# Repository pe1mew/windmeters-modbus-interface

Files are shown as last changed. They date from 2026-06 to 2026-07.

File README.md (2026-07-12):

# Windmeters Modbus Interface

A CH32V003-based interface board that bridges classic analog wind sensors —
a **cup anemometer** (reed-relay pulses) and a **wind-vane potentiometer**
(0–360°) — onto **Modbus RTU over RS-485**, powered by 24 V passive PoE and
designed for daisy-chained field buses.

One PCB serves both sensor types; the firmware build selects the variant.
Each variant responds at its own Modbus address, selected by a solder
jumper:

| Variant | Jumper open | Jumper bridged |
|---|---|---|
| Wind speed (`wind_speed`) | **30** | 35 |
| Wind direction (`wind_direction`) | **31** | 36 |
| Both, one slave (`wind_combined`) | **32** | 37 |

The `wind_combined` build serves both sensors through a single Modbus
address; its register map carries speed and direction at their own
register addresses, with the direction raw-ADC diagnostic at 30013 (30005
holds the speed pulse count).

## Project status (2026-07)

| Area | State |
|---|---|
| Requirements | [`design/TDS.md`](design/TDS.md) **v0.9** — 69 active requirements (incl. FR-S39 persistence, FR-S40 runtime calibration) + §4 as-built hardware from the KiCad PCB, hardened by multi-agent audits + verification passes |
| Drivers | Pulse counting, ADC/circular-mean, Modbus RTU — all HIL-verified on silicon ([`design/driverDevelopment.md`](design/driverDevelopment.md)) |
| Product firmware | Integration stages A–F complete; **TDS-functionally complete** on all three variants (speed, direction, combined), acceptance suite green ([`design/integrationPlan.md`](design/integrationPlan.md)) |
| Hardware/HIL | KiCad schematic/PCB in design; **§9.1 MAX3485-rig HIL complete on all three variants**; real-PCB rows (§9.2) pending |
| Release | Firmware version 1 not yet tagged ([`software/firmware/RELEASES.md`](software/firmware/RELEASES.md)) |

## Hardware

- **MCU**: WCH CH32V003J4M6 (RISC-V, SOP-8, 16 KB flash / 2 KB RAM) — the
  8-pin package drives the whole design: single-wire UART discipline,
  remap tricks, and a zero-interrupt firmware architecture
  ([`design/softwareArchitecture.md`](design/softwareArchitecture.md)).
- **RS-485**: MAX3485; DI+RO tied to PD6, DE+R̄Ē tied to PC2 with a 10 k
  pull-down (keeps the bus safe during reset/flashing); 120 Ω terminator
  behind a solder jumper; A/B fail-safe bias; SM712 TVS.
- **Power**: 24 V passive PoE on the spare pairs (4/5 = +, 7/8 = −) →
  DB207 bridge (polarity protection only) → HLK-K7803 buck → 3.3 V.
- **Connectors**: 2× RJ45 for the daisy-chained bus, two RJ14 sensor jacks
  (anemometer + wind direction), 3-pin header for the WCH-LinkE programmer
  (SWIO on PD1).

## Modbus register map (summary)

12 input registers (FC04) and 6 holding registers (FC03/06/16); registers
of an absent sensor read 0, and the combined build adds a 13th input
register (30013, direction raw ADC). Highlights: instantaneous and averaged
values, status bits, identification (build + firmware version), uptime,
CRC/served counters, gust, seconds-since-last-pulse.
**6** holding registers: direction offset, measurement window, averaging
window, low-speed cut-off, and the anemometer calibration (factor C +
pulses-per-rotation, FR-S40 — so one image serves any anemometer, set over
Modbus). All **persisted in flash across reset/power-loss** (FR-S39); the §2.8
defaults apply only on first boot / erased store. The authoritative map with
ranges, defaults, and requirement IDs is [`design/TDS.md`](design/TDS.md)
§2.7/§2.8.

## Repository layout

| Path | Contents |
|---|---|
| [`design/`](design/README.md) | The design-document chain (index in [`design/README.md`](design/README.md)): scratchBook → TDS → softwareArchitecture (+ UML diagrams in `design/diagrams/`) → driverDevelopment → integrationPlan |
| `hardware/KiCad/` | Schematic + PCB (KiCad); symbol libraries as git submodules |
| `hardware/Documentation/` | Component datasheets (HLK-K78xx, DB20x, Kradex enclosure, …) |
| `software/firmware/` | Product firmware (PlatformIO + ch32v003fun), three build envs (speed / direction / combined) + `_test` variants |
| `software/drivers/` | Standalone driver projects with HIL test shells (the verified libraries the product references in place) |
| `software/hil/` | Scripted hardware-in-the-loop harness: Saleae Logic 2 (MCP) + ADALM2000 (libm2k) + `acceptance/` pytest suite; consolidated [`testReport.md`](software/hil/testReport.md) |
| `Doxyfile` | Doxygen config — builds a single site (design docs + API reference) with this README as the landing page |
| `documentation/` | Chip pinout and project reference images |

Clone with submodules:

```sh
git clone --recurse-submodules https://github.com/pe1mew/windmeters-modbus-interface.git
```

## Building and flashing

Requires [PlatformIO](https://platformio.org/) and a WCH-LinkE on SWIO.

```sh
cd software/firmware
pio run -e wind_speed              # or wind_direction, or wind_combined
pio run -e wind_speed -t upload    # flash via WCH-LinkE
```

Resource ceilings (14 336 B flash / 1 792 B RAM, NFR-RES01) are enforced as
hard build gates. `*_test` environments add bench-only hooks — never
release those binaries. The firmware version byte lives in
`src/version.h`; the release process is documented in `RELEASES.md`.

## Testing

- **Host tests** (no hardware): the circular-mean math is exhaustively
  verified in Python — `python software/drivers/common/circmean/test_circmean.py`.
- **Acceptance suite** (bench: Saleae Logic 2 with its MCP server, ADALM2000,
  WCH-LinkE, TTL Modbus rig):

  ```sh
  cd software/hil/acceptance
  ..\.venv-m2k\Scripts\python.exe -m pytest . --build speed
  ```

  One command per flashed variant; covers the register map, protocol
  vectors, measurement services, averaging engine, version chain, and
  build gates. See [`software/hil/README.md`](software/hil/README.md) for
  instrument setup, wiring, and the bench-quirk catalogue.
- **HIL test report** — [`software/hil/testReport.md`](software/hil/testReport.md)
  consolidates every hardware-in-the-loop test (driver-phase, integration-
  stage, and MAX3485 transceiver rig) with its setup, expected result, and
  pass/fail verdict in one place.

## Documentation

- **Design record** — [`design/README.md`](design/README.md) indexes the
  document chain (requirements → architecture → drivers → integration) and
  the UML diagrams.
- **API + design site** — the firmware headers/sources carry full Doxygen,
  and [`Doxyfile`](Doxyfile) folds the design docs in as pages with this
  README as the landing page. Build the browsable HTML with:

  ```sh
  doxygen Doxyfile        # output in documentation/doxygen/html/index.html
  ```
- **Test evidence** — [`software/hil/testReport.md`](software/hil/testReport.md)
  is the consolidated hardware-in-the-loop test report.

## Related repositories

- [`pe1mew/windmeters-modbus-interface-tester`](https://github.com/pe1mew/windmeters-modbus-interface-tester) —
  the Modbus RTU master bench tool (M5Stack AtomS3 + RS-485) used to
  exercise this device; its bench findings seeded this project's TDS.

## License

Software is provided under a Source-Available Non-Commercial License;
documentation and images under CC BY-NC-ND 4.0. See [LICENSE](LICENSE) and
[license.md](license.md). Third-party datasheets and KiCad library
submodules remain under their owners' terms.

## Author

Remko Welling (PE1MEW)

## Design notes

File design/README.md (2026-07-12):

# Design documentation

This directory holds the design record for the Windmeters Modbus Interface
firmware — the chain from first idea to a validated, requirement-traced
implementation. The documents build on each other in this order:

```
scratchBook  →  TDS  →  softwareArchitecture  →  driverDevelopment  →  integrationPlan
(brainstorm)   (what)   (how + diagrams)         (drivers + results)   (product fw + results)
```

## The documents

| Document | Purpose | Status |
|---|---|---|
| [`TDS.md`](TDS.md) | **Technical Design Specification** — the requirements contract (FR-MB…, FR-S…, NFR-…) with measurable pass/fail criteria. The single source of truth for behaviour. | **v0.9** — 69 active requirements + §4 as-built hardware (from the KiCad PCB); hardened by a multi-agent audit + verification passes |
| [`softwareArchitecture.md`](softwareArchitecture.md) | **How** the requirements are met: the zero-ISR cooperative super-loop, the module split (capability-macro variant gating incl. `wind_combined`), and the sizing rationale with as-built numbers. §7 embeds the UML diagrams. | Agreed baseline; updated 2026-07-12 for the three-variant firmware |
| [`driverDevelopment.md`](driverDevelopment.md) | Plan + results for the three standalone drivers (pulse counting, ADC/circular-mean, Modbus RTU), each HIL-verified before integration. | Phases 0–3 complete, HIL-verified on silicon |
| [`integrationPlan.md`](integrationPlan.md) | The product-firmware plan: six integration stages (A–F) and the §9 hardware-gated test set (MAX3485 rig + real PCB). Carries per-stage results. | Stages A–F done; §9.1 complete on all three variants; §9.2 (real PCB) pending |
| [`scratchBook.md`](scratchBook.md) | The brainstorm and working notes that seeded the TDS — components, power chain, ADC strategy, calibration derivation. Superseded by the docs above where they overlap. | Working notes (historical) |
| [`diagrams/`](diagrams/) | UML diagrams as PlantUML sources + rendered PNGs (see below). | — |

## Diagrams

Three UML views of the shipped design live in [`diagrams/`](diagrams/) and
are embedded in [`softwareArchitecture.md`](softwareArchitecture.md) §7:

- **[`component.puml`](diagrams/component.puml)** — module structure & data
  flow (sensor → driver → measurement → `regs` hub → Modbus).
- **[`superloop_sequence.puml`](diagrams/superloop_sequence.puml)** — one
  zero-ISR super-loop iteration.
- **[`modbus_state.puml`](diagrams/modbus_state.puml)** — the Modbus RTU
  line-discipline state machine.

Regenerate the PNGs with the local PlantUML:

```sh
"C:/apps/plantuml/plantuml.exe" -tpng -o . design/diagrams/*.puml
```

## Build variants

The firmware compiles into three variants from one source tree (FR-S01),
selected by a `-D SENSOR_WIND_*` define and addressed by a PC4 solder jumper:

| Variant | Build type | Address (open / bridged) |
|---|---|---|
| `wind_speed` | 0x01 | 30 / 35 |
| `wind_direction` | 0x02 | 31 / 36 |
| `wind_combined` | 0x03 | 32 / 37 |

## How this connects to the rest of the repo

- The **API reference** ([`Doxyfile`](../Doxyfile) at the repo root) folds
  these design documents in as pages alongside the header/source
  documentation — run `doxygen Doxyfile` for a single browsable site with
  the project [`README.md`](../README.md) as its landing page.
- The requirements here are verified by the scripted bench in
  [`software/hil/`](../software/hil/); every executed test with its
  setup/expected/verdict is consolidated in
  [`software/hil/testReport.md`](../software/hil/testReport.md).
- Contribution workflow (requirements-first, build all variants, run the
  host + acceptance tests) is in [`contributing.md`](../contributing.md).

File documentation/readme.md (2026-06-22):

# WCH MCU documentation on the web

 - https://github.com/limingjie/WCH-MCU-Pinouts/tree/main

# Source downloaded PDF

 - https://www.olimex.com/Products/RISC-V/WCH/WCH-LinkE/resources/WCH-LinkUserManual.PDF
 
# Wiring WCH-Link 

## to nanoCH32V003

```
        nanoCH32V003             WCH-LinkE
      +--------------+    +----------------+
      |              |    |                |
      |          GND o----o GND            |
      |          DI0 o----o SWDIO/TMS      |
      |          VCC o----o 3V3            |
      |              |    |                |
      +--------------+    +----------------+
```

## CH32V003 J4M6 D03

You need a WCH-LinkE programmer to flash this MCU. You connect SWIO to PD1 (pin 8), VDD to pin 4 and VSS to pin 2.

```
     CH32V003J4M6D03             WCH-LinkE
   +-----------------+    +----------------+
   |                 |    |                |
   |         VSS (2) o----o GND            |
   |         PD1 (8) o----o SWDIO/TMS      |
   |         VDD (4) o----o 3V3            |
   |                 |    |                |
   +-----------------+    +----------------+
```

# Platformio an the WCH CH32V Platform

 - https://ch405labs.net/ch32v003_intro/

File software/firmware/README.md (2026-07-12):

# Firmware — Windmeter Modbus interface

PlatformIO project for the **CH32V003J4M6** (RISC-V, SOIC-8, 16 KB flash /
2 KB RAM). One unmodified PCB runs every variant; the sensor build is chosen
at compile time (TDS FR-S01/FR-S02).

Authoritative references: the register map and behaviour contract live in
[`design/TDS.md`](../../design/TDS.md) (§2.7 input / §2.8 holding registers,
§4 as-built hardware and pin assignment); the zero-ISR super-loop design and
module split in
[`design/softwareArchitecture.md`](../../design/softwareArchitecture.md).

## Build environments

| Environment | Define | Sensor(s) | Build byte | Address (PC4 open / bridged) |
|---|---|---|---|---|
| `wind_speed` | `SENSOR_WIND_SPEED` | cup anemometer | `0x01` | **30** / 35 |
| `wind_direction` | `SENSOR_WIND_DIRECTION`  | wind-vane potentiometer | `0x02` | **31** / 36 |
| `wind_combined`  | `SENSOR_WIND_COMBINED` | both, behind one slave | `0x03` | **32** / 37 |

`sensors.h` maps the selector onto capability macros
(`HAVE_WIND_SPEED` / `HAVE_WIND_DIRECTION`); the combined build defines both.
Each variant also has a **`*_test`** environment adding `-D TEST_HOOKS` — the
FR-S20 watchdog hang trigger (holding `0x00FF`, magic `0xDEAD`) used by the
HIL persistence/reset checks. **Never release a `*_test` binary.**

## Prerequisites

- [PlatformIO Core](https://platformio.org/install/cli) (`pip install platformio`)
  or the PlatformIO VS Code extension.
- A **WCH-LinkE** programmer on SWIO (PD1, the 3-pin header J2).

The community WCH platform (`platform = ch32v`) and the `ch32v003fun`
framework are pulled automatically on first build. The verified driver
libraries (`ws_*`, `wd_*`, `mb_*`, `circmean`) are referenced **in place**
from [`software/drivers/`](../drivers/) — no copies.

## Usage

```sh
pio run                            # build default env (wind_speed)
pio run -e wind_combined           # build the combined variant
pio run -e wind_combined -t upload # flash via WCH-LinkE
```

There is no serial console: the release firmware never transmits unsolicited
(FR-S19) — PD6 is the Modbus data line. Talk to a flashed device over
RS-485/Modbus RTU (9600 8N1), e.g. with the
[`windmeters-modbus-interface-tester`](https://github.com/pe1mew/windmeters-modbus-interface-tester)
as master.

## Resource ceilings (NFR-RES01)

The 87.5 % ceilings — **14 336 B flash / 1 792 B RAM** — are hard build gates
(`board_upload.maximum_size` / `maximum_ram_size`); a build that exceeds them
fails. As-built (fw v1, with FR-S39 persistence + FR-S40 calibration):

| Variant | Flash | RAM |
|---|---|---|
| `wind_speed` | 4 408 B (31 %) | 908 B (51 %) |
| `wind_direction` | 6 824 B (48 %) | 916 B (51 %) |
| `wind_combined` | 7 604 B (53 %) | 1 216 B (68 %) |

## Configuration and calibration

All six holding registers (40001–40006) are runtime-writable and **persist in
flash across reset/power-loss** (FR-S39). The anemometer calibration
(FR-S40) is register-driven — factor C in 40005, pulses-per-rotation in
40006 — so one binary serves any anemometer with no rebuild. The compile-time
defaults that seed those registers on first boot can be overridden per build:

```ini
build_flags = ... -D WS_C_SCALED=980 -D WS_PULSES_PER_ROTATION=1
```

## Versioning and releases

The firmware version byte (reported in input register 30007, low byte) has a
single source: [`src/version.h`](src/version.h). Releases are registered in
[`RELEASES.md`](RELEASES.md); firmware version 1 will be tagged `fw-v1`.

## Testing

- **Host tests** (no hardware): `python ../drivers/common/circmean/test_circmean.py`.
- **Acceptance suite** (bench, one command per flashed variant):

  ```sh
  cd ../hil/acceptance
  ..\.venv-m2k\Scripts\python.exe -m pytest . --build combined
  ```

  Instrument setup, wiring, and the bench-quirk catalogue are in
  [`software/hil/README.md`](../hil/README.md); every executed HIL test with
  its verdict is consolidated in
  [`software/hil/testReport.md`](../hil/testReport.md).

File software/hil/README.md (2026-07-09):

# HIL test harness

Scripted hardware-in-the-loop testing per `design/driverDevelopment.md` §2.3/§2.5:
flash (`pio`) → stimulate (ADALM2000 / libm2k) → observe (Saleae Logic 2 MCP)
→ assert (Python).

> **Consolidated results:** [`testReport.md`](testReport.md) is the single
> record of every HIL test with its setup, expected result, pass criteria,
> and verdict. This README covers *how* to run the harness (instruments,
> wiring, quirks); the test report covers *what was tested and the outcome*.
> Regenerate the report when the check scripts or the design docs change.

## Instruments

| Instrument | Interface | Role |
|---|---|---|
| Saleae Logic16 (classic, digital-only) | Logic 2 built-in MCP server, `http://127.0.0.1:10530/mcp` (JSON-RPC/HTTP) | Observer: digital captures, protocol analyzers, CSV export |
| ADALM2000 (M2K) | libm2k (Python 3.11 venv) | Stimulus: pulse trains, bursts, DC levels/ramps, programmable supply; its scope verifies analog |
| WCH-LinkE | `pio run -t upload` (`%USERPROFILE%\.platformio\penv\Scripts\pio.exe`) | Flash + 3.3 V DUT power + UART monitor RX |

## Python environments

- Saleae scripts are **stdlib-only** — any Python ≥3.10 works (system 3.13 fine).
- libm2k wheels top out at **cp311**, and the wheel alone is not enough —
  it needs the system-installed libm2k/libiio DLLs. Setup (one-time):
  1. Run `PlutoSDR-M2k-USB-Drivers.exe` (admin) — IIO/RNDIS USB drivers.
  2. Run `libm2k-0.9.0-Windows-setup.exe` (admin) — runtime DLLs.
  3. `python3.11 -m venv .venv-m2k` and
     `.venv-m2k\Scripts\pip install libm2k-0.9.0-cp311-cp311-win_amd64.whl`
     (wheel from the libm2k GitHub release `python-wheels.zip`).

## Scripts

| Script | Purpose | Status |
|---|---|---|
| `smoke_test.py` | Saleae MCP link: devices, capture, export | PASS 2026-07-03 |
| `blinky_check.py` | Flash→capture→assert chain on the DUT (blinky timing) | PASS 2026-07-03 (ch8) |
| `uart_check.py` | debug_uart §2.2 exit criterion (async-serial decode) | PASS 2026-07-03 |
| `m2k_smoke.py` | M2K reachable, calibrated, subsystems up | PASS 2026-07-03 (fw v0.33) |
| `m2k_signal_check.py` | Generate + verify every driver-phase stimulus signal | PASS 2026-07-03, 15/15 |
| `saleae_serial.py` | Shared module: UART capture + timestamped line decode | library |
| `ws_check.py` | Wind speed driver phase-1 matrix (counts, duty, timing, saturation) | PASS 2026-07-03, 9/9 |
| `wd_check.py` | Wind direction phase-2 matrix (AWG-based; superseded for accuracy rows by the divider method — see README notes) | superseded 2026-07-03 |
| `mb_check.py` | Modbus RTU phase-3 matrix (26 vectors, TDS §2) + timing; M2K as open-drain bit-banged master | PASS 2026-07-03, 26/26 + 40/40 endurance |
| `rs485_check.py` | MAX3485-rig passive judge of live master traffic: DE timing, storm, idle-bias, latency, wire CRC both directions | PASS 2026-07-06, 8/8 (117 transactions) |
| `rs485_regs_check.py` | Full TDS §2.7/§2.8 register read/write matrix over RS-485 via the tester's machine API; `--build speed\|direction\|combined` | PASS: speed 62/62, direction 72/72 (2026-07-06), **combined 77/77** (2026-07-08, `--speed-live`) |
| `rs485_raw_check.py` | Byte-exact §9.1 vectors via second-MAX3485 raw master: split frames, garbage floods, off-baud, 1000-request latency histogram | PASS 2026-07-06, all groups (both builds) |
| `m2k_pulse.py` | M2K W2 (AWG) → PC1 speed pulse train; holds the context open (+V+ keepalive) so another process runs the matrix concurrently | used for combined `--speed-live` |
| `rs485_float_check.py` | FR-S38 wind-direction float-fault + recovery over RS-485 (`--expect fault\|driven`, `--build direction\|combined`) | PASS 2026-07-08, fault 4/4 + recovery 4/4 |
| `rs485_persist_check.py` | FR-S39 holding-register persistence across a watchdog reset (`*_test` build); write → reset → assert settings survive | PASS 2026-07-08, 7/7 |
| `m2k_vplus_check.py` | DUT powered from M2K V+: ratiometric ADC VDD sweep (P2-WD-RATIO) + FR-S39 persistence across a real power cycle. Guards against driving V+ into a live LinkE rail | PASS 2026-07-09, 6/6 |

## Bench wiring notes

- Saleae Logic16 lead labels ≠ channel indices (two 8-lead banks). DUT PD6
  is currently on **channel 8**. After rewiring, locate signals with an
  all-channel sweep capture first.
- `m2k_signal_check.py` rig: M2K DIO0 → Saleae **channel 15** (current bench);
  M2K W1 → M2K 1+; M2K V+ → M2K 2+; all grounds common (M2K, Saleae, LinkE,
  DUT).
- Keep M2K AWG outputs configured 0–3.3 V near the DUT (hardware can swing
  ±5 V — beyond CH32V003 absolute maximums).
- **MAX3485 rig (2026-07-06)**: DUT transceiver DI+RO → PD6 (Saleae ch8 on
  that node), DE+R̄Ē → PC2 (ch15) with the 10 k pull-down; bus A/B → M2K
  scope 1+/2+ for the analog wire view. **Second MAX3485 as raw master**:
  M2K DIO0 → DI, DIO1 → DE+R̄Ē, **V+ → VCC (3.3 V)** — every raw-master
  script must enable V+ itself (`ps.enableChannel(0, True)` +
  `pushChannel(0, 3.3)`): an unpowered MAX3485 sits inert and the static
  DE/DI test (drive space, drive mark, release) is the 10-second wiring
  proof. The `windmeters-modbus-interface-tester` on the same bus is both
  a third node and a scriptable well-formed master (machine API, see its
  `manual/api.md`).

## MAX3485-rig lessons (2026-07-06, learned the hard way)

- **The tester never stops listening.** Its Modbus master only drains its
  UART RX during its own transactions, so it buffers every byte the raw
  master puts on the shared bus; its next transaction then parses the
  stale backlog and reports CRC_ERR (log showed ~30 overheard frames
  ahead of the true response). One throwaway read IS the flush — retry
  once on `crc_error` before trusting a tester-API read after raw-master
  traffic (`rs485_raw_check.dut_diag`).
- **Inter-frame marks in composed patterns must exceed t3.5 (4.01 ms).**
  A 2.5 ms gap between a garbage tail and the recovery request made the
  DUT (correctly) coalesce them into one discarded frame — 48 bit times
  of mark (5 ms) is the house gap.
- **Noise floods don't move the DUT's CRC counter** — random bytes arrive
  framing-poisoned (FE/overflow) and take the silent-discard path;
  only cleanly-framed-wrong-CRC frames (e.g. split halves) increment
  30009. Assert flood recovery by behavior, not by that counter.
- The DUT answers master baud offsets to ±3 % in both directions
  (measured with the rate read back from the ladder); its own HSI adds
  ~+0.3 %.

## M2K / libm2k quirks (learned on the bench, fw v0.33 + libm2k 0.9.0)

- **Firmware ≥0.32 is mandatory** for libm2k 0.9.0 (shipped fw v0.27 gave
  erratic AWG output and version errors). Update: copy `m2k.frm` from the
  m2k-fw release onto the M2K mass-storage drive and eject; it self-flashes
  (~1 min, don't unplug).
- **Analog-out session-state corruption**: within one context, repeated
  output reconfiguration misbehaves — `stop()` wedges the DAC until
  `reset()`; a second cyclic `push()` at the same sample rate is silently
  ignored; non-cyclic pushes and `setVoltage()` inherit stale state. The
  reliable pattern is a **fresh `m2kOpen()` + calibrate per analog stimulus
  configuration** (~1.5 s each). Digital out is unaffected.
- Rapid close/reopen can transiently fail ("Cannot set the number of kernel
  buffers") — retry with ~1 s backoff (`open_calibrated()` helper).
- **Pattern generator start stub**: the first period after `push()` is
  anomalous; frequency/duty measurements must judge steady state only.
- **Large cyclic digital buffers get truncated** (1 Hz @ 1 MS/s ran 6%
  fast) — scale the sample rate to keep one period at ~10k samples.
- AWG sample rates snap to a discrete ladder (75 MS/s / 10ⁿ); at low rates
  the DC output droops between buffer wraps — generate DC at 750 kS/s or
  via `setVoltage()`.
- Absolute AWG+scope accuracy stacks badly — DMM-anchored on this unit:
  the **AWG outputs setpoint +25 mV** (constant), the **scope reads
  ~1%/−30 mV low** (affine, drifts ~10 mV between sessions). Never assert
  DUT accuracy against M2K absolute voltages; use a **resistor divider
  from DUT VDD** (ratiometric, DMM-measured ratio) as the method of
  record. The M2K remains fine for dynamics, end stops, and anything
  ratio-cancelled.
- **Keep the libm2k context OPEN while the DUT-side capture runs**:
  `contextClose()` idles the AWG outputs. Measure-then-close-then-capture
  silently tests a dead stimulus (cost a full debugging afternoon).
- A "disabled" AWG channel is NOT high-impedance (~50 Ω to its idle
  level) — it cannot emulate a disconnected sensor for float-detection
  tests; physically lift the wire instead.

## Saleae MCP quirks (learned on the bench)

- `add_analyzer` settings need tagged values: `{"Input Channel": {"numberValue": 8}}`.
- `export_raw_data_csv` requires `analogDownsampleRatio` even for digital-only.
- Async-serial data-table CSV holds the *literal* character per byte — CR/LF
  arrive as embedded newlines inside quoted fields; don't strip.
- A capture that starts mid-byte yields garbage + one framing error before
  the first line boundary — judge from the first clean `\n` onward.
- Classic Logic16 rejects `digitalThresholdVolts` values — omit it (default
  range suits 3.3 V logic).

## Modbus TTL-rig lessons (phase 3, learned the hard way)

- **The Logic 2 Async Serial analyzer is unreliable at 9600 baud** on this
  setup — byte values scramble while the raw edges are perfect. Binary
  protocols use `saleae_serial.uart_decode()` (software UART over the raw
  edge export) instead. Also: `decode_events(..., sync_to_newline=False)`
  for binary — the text-protocol first-LF rule silently discards
  LF-free captures.
- **M2K as shared-wire master: use open-drain output mode**
  (`setOutputMode(DIO_OPENDRAIN)` + the external pull-up), permanently
  enabled. The tristate dance (direction flips per transaction) sprays
  break glitches and phantom start bits; `push()` starts can still glitch —
  keep a ~10 ms driven-high lead-in so any phantom byte orphans behind a
  t3.5 gap.
- **A master must release the wire immediately after its last stop bit** —
  the DUT replies ~5 ms later; holding the line driven collides with the
  reply.
- DUT-side registers exposing error counters and a last-bad-frame stash
  are worth their flash cost many times over: the stash is what proved
  "first byte swallowed" and later "ISR corruption" beyond argument.

## DUT-side UART gotchas (learned on the bench)

- **HDSEL idles the line floating**: in half-duplex mode the USART releases
  TX between frames; a lightly-loaded pin drifts low and every following
  frame decodes with framing errors. `common/debug_uart` therefore runs
  plain TX (idle mark driven). Continuous streams mask this — it only bites
  bursty output.
- **HDSEL also intermittently swallows the first RX byte after idle**
  (~35%, no error flags) — the Modbus driver abandoned HDSEL entirely for
  a remap-switching discipline (RX on PD6 via the default map; TX remapped
  in only for the response). See `software/drivers/modbus_rtu/README.md`.
- **Interrupts are suspect on this toolchain path**: an RXNE ISR corrupted
  ~1/3 of received frames with no USART error flags; polled RX fixed it
  outright. The architecture is now zero-ISR
  (`design/softwareArchitecture.md`) — root-cause before ever adding one.
- **ch32v003fun SysTick default is HCLK/8**: define
  `FUNCONF_SYSTICK_USE_HCLK 1` when pacing with raw `SysTick->CNT` math, or
  everything runs 8× slow.
- Count-vs-frequency asserts must scale to the **measured** window duration
  (report-line timestamp deltas): the DUT window is HSI-paced (±1%), so at
  1 kHz a nominal-window compare is off by several counts while the DUT is
  behaving exactly per FR-S06.

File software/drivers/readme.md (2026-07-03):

# Drivers for CH32V003J4M6

Here are the individual drivers for teh project using a CH32V003J4M6.

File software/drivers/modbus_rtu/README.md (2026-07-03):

# Modbus RTU slave driver — USART1 on PD6, DE/RE on PC2

Phase-3 driver per `design/driverDevelopment.md` §5. Implements the TDS §2
driver layer: framing/CRC, t3.5 gap detection, address filtering,
FC03/04/06/16, standard exceptions, no-clamp range rejection, atomic FC16,
quantity validation, big-endian data / little-endian CRC, FC06 echo & FC16
confirm responses, and app-owned register semantics (holding table with
min/max, input-read callback, cross-validate hook for FR-S31).

## HIL verification — PASS 2026-07-03 (TTL rig, no transceiver)

`software/hil/mb_check.py`, M2K as bit-banged open-drain master on the
shared PD6 wire, Saleae raw-edge decode:

- **26/26 matrix vectors** covering FR-MB02/05/06/08–15/19/22/25/28/30 and
  FR-S31 cross-register constraint via the hook
- **40/40 endurance transactions**, zero loss
- **Response latency: median 5.2 ms, worst 5.2 ms** (FR-MB21 typical <15 ms,
  FR-MB20 hard <100 ms)

Deferred to the MAX3485 rig / acceptance: FR-MB04 DE-timing scope asserts
(PC2 is on Saleae ch15, not yet asserted), FR-MB24 garbage-flood and
oversize-frame vectors, FR-MB03 split-frame timing vectors, RS-485
electrical rows.

## Two hard-won design decisions (bench-forced, both product-relevant)

**1. No HDSEL — remap-switching line discipline.** In HDSEL single-wire
mode this part intermittently (~35%) swallowed the FIRST byte after bus
idle with no error flags (wire verified pristine at 10 MS/s; the stashed
frame was the request minus its address byte). Instead the driver uses the
SOP-8 remap geometry: the DEFAULT USART map has **RX natively on PD6**;
`mb_send()` temporarily switches to partial remap 2 (TX→PD6), transmits,
and switches back. Modbus is strictly request/response, so the direction is
always known. Side benefit: no self-echo during reception (FR-MB23
satisfied by flag-clearing around the TX window).

**2. Polled RX — zero interrupts.** With the RXNE ISR, ~1/3 of frames
reached the parser with missing/scrambled leading bytes while the USART
never flagged an error — symptoms of ISR prologue/state corruption on this
toolchain path (`__attribute__((interrupt))` on RV32EC, unconfirmed root
cause; treat ANY interrupt use in this project as suspect until
investigated). Polling from the main loop (~1 µs cycle vs 1042 µs per
byte) is provably lossless and removed every failure instantly:
26/26 + 40/40 vs the ISR build's chaos. `softwareArchitecture.md` is
amended accordingly.

## Diagnostics (exposed as shell input registers)

`mb_crc_error_count` / `mb_served_count` (future 30009/30010), plus bench
registers: FE/NE/ORE counters and a last-CRC-fail frame stash (len, first
bytes, received CRC) — the stash is what cracked the first-byte-loss hunt.

## API (`lib/mb/`)

```c
mb_config_t cfg = {.address, .holdings, .n_holdings,
                   .input_read, .cross_validate};
void mb_init(const mb_config_t *cfg);
void mb_poll(void);   // main loop; self-timed via SysTick->CNT
```

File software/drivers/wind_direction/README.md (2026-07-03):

# Wind direction driver — 10-bit ADC on PA2, oversampled, circular mean

Phase-2 driver per `design/driverDevelopment.md` §4. Reads the wind-vane
potentiometer ratiometrically (TDS FR-S09), 16× oversampled (FR-S28), with
wiper-float detection (FR-S38). The circular mean lives in
`software/drivers/common/circmean/` (Q15 sine table + integer CORDIC,
exhaustively host-tested + boot self-test on target).

## HIL verification — PASS 2026-07-03

Method of record for accuracy: **resistor divider powered from DUT VDD**
(ratiometric, cancels VDD, kΩ source like the real pot — exactly FR-S11's
method). AWG-based absolute-voltage tests proved unusable for accuracy: the
M2K AWG has a +25 mV output offset and the M2K scope reads ~1%/−30 mV low
(both DMM-anchored), stacking to a fake ±16 LSB "bow".

| Row | Result |
|---|---|
| Accuracy (FR-S11) | −3.8 LSB at divider ratio 0.49899 (9.92k/9.88k, DMM-measured); budget ±10 LSB. Full 5-ratio sweep deferred to acceptance. |
| Stability (FR-S10/S28) | raw16 span 0.6 LSB over 11 s (≤3 required) |
| End stops (FR-S09) | pin→GND: code 0.0; pin→VDD: code 1023.0 — exact |
| Never 3600 (FR-S29) | angle 3596 at the VDD rail, by construction |
| Float detect (FR-S38) | truly open pin: flt=1 every window; pot-like 4.95 kΩ source: flt=0; 50 Ω source: flt=0 |
| Circular mean (FR-S14) | host: identity 0 LSB over all 3600 angles, CORDIC ≤0.0035°, 350°/10°→0.0°; on-target boot self-test CM,PASS |

Deferred to integration/acceptance: 5-ratio accuracy sweep, M2K-powered VDD
sweep (explicit ratiometric-sanity row), offset register wrap via Modbus
(FR-S12 — logic host-proven).

## Bench findings that shaped the driver

- **ADC clock**: HCLK/8 = 6 MHz (`RCC_ADCPRE_DIV8` — the ADCPRE field is
  NOT a plain binary divider; use the named constants). At /2 = 24 MHz the
  part appeared to bow at range ends; later attributed mostly to
  instrument stack, but /8 costs nothing here (~14 µs/conversion, 224 µs
  per 16-burst vs the 100 ms update budget).
- **Float detector**: pull-toggle with 10 µs settle discriminates cleanly:
  truly open pads swing >700 LSB; a 5 kΩ pot moves ~100 LSB (threshold 300).
  A "disconnected" AWG does NOT read as floating — its disabled output is
  still ~50 Ω.
- **The angle mapping never emits 3600**: (raw16×3600+8192)>>14 tops out
  at 3596 at code 1023 — verified at the rail.

## API (`lib/wd/`)

```c
void     wd_init(void);            // ADC on, self-calibrated, 73-cycle sampling
uint16_t wd_read_raw16(void);      // sum of 16 conversions: 0..16368
uint16_t wd_angle_0_1deg(uint16_t raw16, uint16_t offset_0_1deg); // 0..3599
bool     wd_wiper_floating(void);  // FR-S38 pull-toggle test
```

## Test shell output (PD6 debug UART, 115200)

```
CM,PASS               boot self-test of circmean on the target CPU
WD,START
D,<raw16>,<inst>,<avg>,<flt>    per second; angles in 0.1°
```

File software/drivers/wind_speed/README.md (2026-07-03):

# Wind speed driver — TIM2 ETR pulse counting on PC1

Phase-1 driver per `design/driverDevelopment.md` §3. Counts anemometer
reed-relay pulses in hardware (zero CPU per pulse, TDS FR-S04) using TIM2 in
external-clock mode 2 on PC1.

## HIL verification — PASS 2026-07-03 (9/9)

`software/hil/ws_check.py`, M2K DIO0 driving PC1, report stream decoded off
the Saleae:

| Row | Result |
|---|---|
| Counts 1 / 10 / 100 / 1000 Hz | exact, scaled to the measured window |
| Rising edges only (10% / 90% duty) | identical counts (FR-S04) |
| Window pacing | worst 3.35 ms deviation on 1000 ms = 0.34% (FR-S17 ±2%) |
| Saturation (100 kHz × 1 s = 100k edges) | reports 65535 + `S` flag, never a wrapped value (FR-S27) |
| Silence (line low / open with pull-up) | 0 counts |

Outstanding (hardware-dependent): reed-relay bounce realism through the RC
debounce — run when a physical reed relay is on the rig.

## The remap (the phase's big unknown — confirmed on silicon)

`AFIO_PCFR1[9:8] = 10` (TIM2 partial remap 2) places TIM2_CH1/ETR on PC1 —
the only mapping that reaches PC1 on the SOP-8. Configured in `ws_init()`
with a read-modify-write that preserves the USART1 remap bits. TIM2 then
runs in external clock mode 2 (`SMCFGR = TIM_ECE`, rising edges, no input
filter — the product's RC network debounces externally).

## API (`lib/ws/`)

```c
void     ws_init(void);                   // remap + counter running
void     ws_window_start(void);           // CNT=0, clear UIF
uint16_t ws_window_read(bool *saturated); // count; 65535 + flag if UIF set
```

Window pacing is the caller's job (test shell here: SysTick-paced 1000 ms,
`FUNCONF_SYSTICK_USE_HCLK 1` — ch32v003fun's default SysTick clock is
HCLK/8, which silently makes naive tick math 8× slow).

## Test shell output (PD6 debug UART, 115200)

```
WS,START
W,<count>,<flag>      one line per window; flag 0 normal, S saturated
```

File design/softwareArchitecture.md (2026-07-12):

# Software Architecture — Windmeters Modbus Interface

| Field | Value |
|---|---|
| Document | Software architecture (design rationale) |
| Project | `windmeters-modbus-interface` firmware |
| Date | 2026-07-03 (combined-variant update 2026-07-12) |
| Status | Agreed baseline for driver development and integration; updated for the shipped three-variant firmware |
| Related docs | `design/TDS.md` v0.9 (requirements this design satisfies), `design/driverDevelopment.md` (drivers are written against this architecture), `design/integrationPlan.md` §10 (combined variant), `design/scratchBook.md` |

## 1. Scope and constraints

Target: CH32V003J4M6 — RV32EC, one core, 48 MHz HSI, 16 KB flash, 2 KB SRAM.
One firmware source tree, three builds (wind speed / wind direction /
combined, FR-S01). `sensors.h` maps the single `SENSOR_WIND_*` build
selector onto **capability macros** — `HAVE_WIND_SPEED` /
`HAVE_WIND_DIRECTION` — and the combined build simply defines both, so
every per-sensor block compiles in unchanged; nothing below is
combined-specific except where marked.

Given these constraints and the TDS requirements, the architecture is
**zero-interrupt: a cooperative super-loop polls everything.** No RTOS —
it would cost more RAM than the application uses and buys nothing here.

> **Amendment 2026-07-03 (phase-3 bench):** the original design used a
> USART RX ISR + SysTick ISR. On the bench, the RXNE ISR corrupted ~1/3 of
> received frames (missing/scrambled leading bytes, no USART error flags,
> wire verified pristine) — symptoms consistent with interrupt
> prologue/state corruption on this RV32EC toolchain path. Polled RX fixed
> it completely (26/26 matrix + 40/40 endurance). Since the main loop
> cycles in ~1 µs versus 1042 µs per byte at 9600 baud, polling is
> provably lossless and interrupts buy nothing. **Do not introduce ISRs in
> this project without first root-causing that failure** (suspect
> `__attribute__((interrupt))` code generation with ch32v003fun).

## 2. Structure

```
┌─ main loop (everything, run-to-completion, no ISRs) ────────┐
│ for(;;) {                                                   │
│   modbus_service();      // poll RXNE/errors, stamp ticks,  │
│                          // gap detect, parse, respond      │
│   measurement_service(); // per capability macro: speed     │
│                          // and/or direction — a combined   │
│                          // build runs BOTH in this pass    │
│   diagnostics_service(); // uptime, counters                │
│   IWDG_refresh();        // only here (FR-S20)              │
│ }                                                           │
└─────────────────────────────────────────────────────────────┘
   TIM2 (speed/combined): pure hardware counter — counts with zero code
   Timing: raw SysTick->CNT arithmetic (HCLK; FUNCONF_SYSTICK_USE_HCLK 1)
```

Initialization before the loop follows the FR-S18 order strictly:
PC2/DE low first → PC4 address latch → sensor front-end ready (ADC
self-calibration / TIM2 clear) → IWDG on → USART1 receiver enabled last.

*See §7 (below) for the component, super-loop sequence, and Modbus
state-machine diagrams.*

## 3. Key decisions and why

**Everything stateful lives in the main loop.** Modbus registers are written
by `measurement_service()` and read by `modbus_service()` — both in the same
sequential loop, so FR-S24's snapshot coherence is *structural*: no masking,
no double-buffering, no races, because there is no preemption between
producer and consumer. This is the single biggest simplification available,
and it is why measurement does **not** run in the SysTick ISR (superseding
the earlier scratchBook sketch that put it there).

**Frame boundary by polling, not a timer.** The main loop checks
`ms_tick - last_rx_tick ≥ 5` to detect the 3.5-character gap (FR-MB03). A
dedicated t3.5 timer interrupt is the textbook approach, but timers are
scarce (TIM2 is the pulse counter on the speed and combined builds), the
loop iterates thousands of times per millisecond, and the detection jitter
this adds is microseconds against a 100 ms budget (FR-MB20). One mechanism,
all three builds.

**Blocking TX from the main loop.** The longest response (~29 bytes) takes
~33 ms of wire time at 9600 baud. Sending it byte-by-byte with a poll on
TXE, then polling TC to drop DE within one character time (FR-MB04), is
simple and deterministic. It briefly stalls the loop, but well inside the
IWDG window, and Modbus is strictly request/response so nothing else can
arrive meanwhile. Self-echo cannot occur at all in the shipped design: the
remap-switching line discipline (RX native on PD6; TX remapped onto PD6
only for the response, RO tri-stated while DE is high — the HDSEL sketch
was abandoned per the §1 amendment) leaves nothing looped back, and the
receiver re-arms only after DE drops plus a t3.5 idle (FR-MB23).

**No ADC interrupt, no TIM2 interrupt.** Direction path
(direction/combined): every 100 ms the main loop takes 16 blocking
conversions (< 1 ms total at the ≥71-cycle sample time) and folds them per
FR-S28. Speed path (speed/combined): TIM2 counts in hardware; at window
expiry the main loop reads CNT, checks the overflow flag UIF for FR-S27
saturation (no ISR needed — poll the flag at read time), resets, computes,
publishes.

**Combined build: both sensors, one slave, zero new mechanism.** The
capability macros compile *both* measurement services into the same
super-loop pass — they run sequentially, so FR-S24's structural coherence
holds unchanged and there is still no concurrency surface. Each sensor gets
its own averaging cursor in `avg.c` (the two boxcar rings advance
independently, since the speed ring fills per measurement window and the
direction ring per 100 ms update). The extra work per pass is the ADC burst
(< 1 ms) plus the window computation — microseconds-scale against FR-MB20's
100 ms budget; measured response latency through the transceiver is
unchanged (~4.1 ms median). The register image carries both sensors at
their §2.7 addresses; the only map difference is the shared raw-diagnostic
slot: 30005 reports the speed pulse count on a combined build, and the
direction raw ADC moves to the combined-only 30013 (`regs.c`, the one
`SENSOR_WIND_COMBINED`-specific piece of code). Address pair 32/37
(`board.h`, FR-S03).

## 4. Shared state — the complete list

With zero interrupts there is **no concurrency surface at all**: every
variable has exactly one execution context. The RX buffer, tick stamps,
register image, and averaging blocks are all plain main-loop state.
FR-S24's snapshot coherence is absolute by construction.

## 5. Sizing sanity check

**RAM:** 256 B RX + 64 B TX + ~32 B register image + 256 B averaging blocks
(64 × two u16, per FR-S31's two-stage boxcar) + ~512 B stack ≈ **1.1 KB**,
inside NFR-RES01's 1792 B ceiling.

**Flash:** Modbus core ~2–3 KB, bitwise CRC-16 (~100 B — speed is
irrelevant at 9600 baud), fixed-point sin/cos table + CORDIC atan2 for the
circular mean ~1 KB, measurement logic ~1 KB — comfortable in NFR-RES01's
14 336 B ceiling (note: RV32EC has no hardware multiply/divide; libgcc soft
routines are pulled in by the FR-S06 math).

**Latency:** response starts ~5 ms after the frame gap in the typical case
(worst loop iteration is the window-boundary computation, well under 1 ms)
— meets FR-MB21's 95%-within-15 ms with margin, and FR-MB20's 100 ms hard
limit trivially.

**As-built (2026-07-12, fw v1 with FR-S39 persistence + FR-S40
calibration):** speed 4 408 B flash / 908 B RAM; direction 6 824 B / 916 B;
combined 7 604 B / 1 216 B — the largest build sits at 53 % of the flash
ceiling and 68 % of the RAM ceiling (NFR-RES01), so the estimates above
held and the combined variant fits with headroom. Measured latency through
the MAX3485: median 4.12 ms over 1 000 requests (`testReport.md`
R485-LAT-10D).

## 6. Module split

| Module | Contents | Driver-plan origin |
|---|---|---|
| `main.c` | The super-loop and window pacing | integration phase |
| `board.c` | Clocks, GPIO, FR-S18 init order, PC4 address latch, IWDG + PVD | integration phase |
| `sensors.h` | Build selector → capability macros (`HAVE_WIND_SPEED` / `HAVE_WIND_DIRECTION`) + `BUILD_TYPE`; a combined build defines both | integration phase (combined variant) |
| `mb.c` | Framing, CRC, FC dispatch, exceptions, DE control + remap-switching line discipline — referenced in place from `software/drivers/modbus_rtu` | `modbus_rtu` driver (`mb_*`) |
| `regs.c` | Register image + table-driven `{addr, min, max}` validator — FR-MB19/22/28 become one code path; persist load/save wiring; the 30005/30013 combined split | integration phase |
| `meas_speed.c` | TIM2 ETR counting, FR-S06/S40 scaling | `wind_speed` driver (`ws_*`) |
| `meas_dir.c` | ADC oversampling, offset/wrap, fault detect | `wind_direction` driver (`wd_*`) |
| `avg.c` | Boxcar/two-stage averaging + gust (FR-S31/S37), one cursor per sensor | integration phase (stage E) |
| `persist.c` | FR-S39 holding-register persistence — two-page flash ping-pong, power-loss atomic | integration phase |
| `circmean.c` | Fixed-point sin/cos + atan2 (host-unit-tested) — referenced in place from `software/drivers/common` | `common/circmean` |
| `debug_uart.c` | PD6 TX-only tracing (driver phases only; absent from release builds) | `common/debug_uart` |

`meas_speed.c` / `meas_dir.c` compile in per capability macro: the
single-sensor builds get one of them, the combined build gets both — each
publishing through its own `avg.c` cursor into the shared `regs.c` image.
Driver development happens standalone per `design/driverDevelopment.md`;
this document is the contract the drivers integrate back into.

## 7. Diagrams (UML)

These reflect the **shipped** implementation — zero-ISR, remap-switching
line discipline, three build variants (speed / direction / combined), and
FR-S39 holding-register persistence — matching the text above (updated
2026-07-12 for the combined variant). Sources live in
[`design/diagrams/`](diagrams/) as PlantUML; regenerate the PNGs with:

```sh
"C:/apps/plantuml/plantuml.exe" -tpng -o . design/diagrams/*.puml
```

### 7.1 Component diagram — module structure & data flow

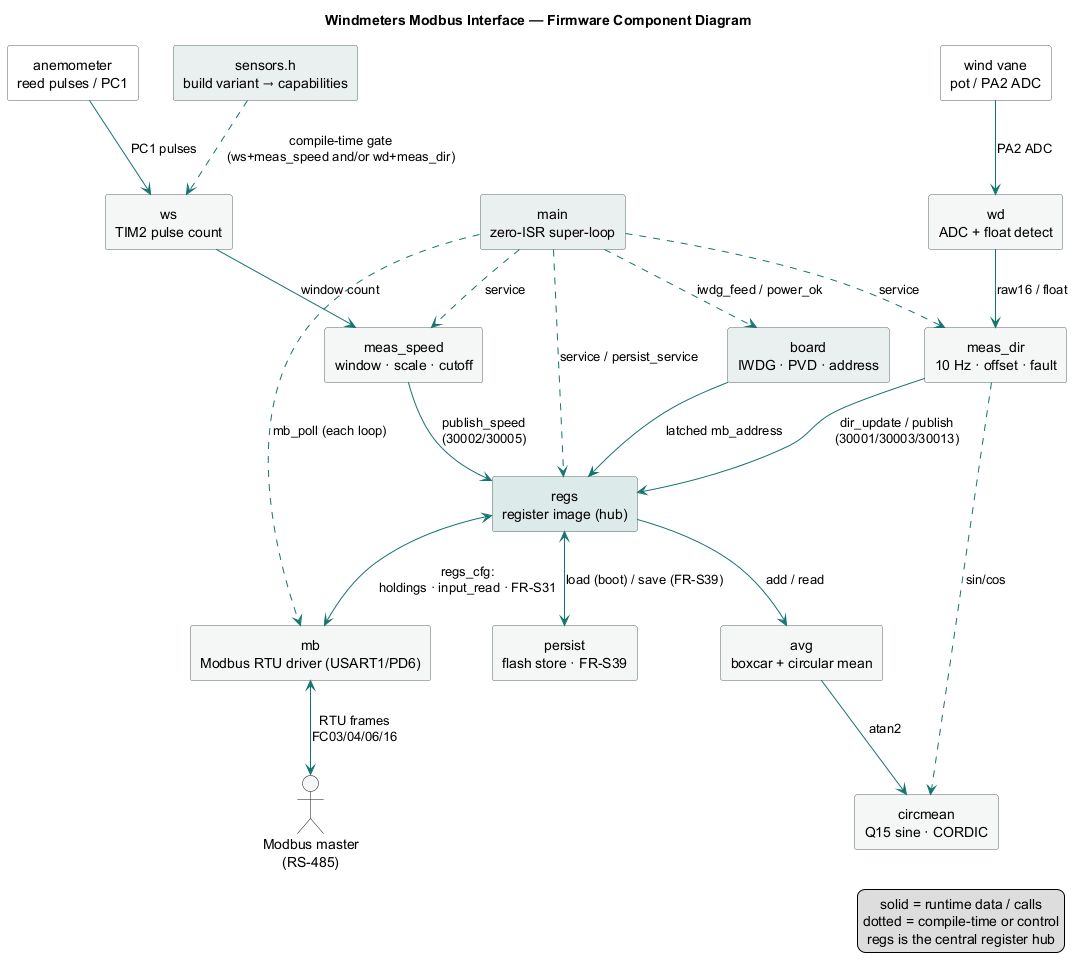
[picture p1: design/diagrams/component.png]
Firmware component diagram


Source: [`diagrams/component.puml`](diagrams/component.puml). The sensor →
driver → measurement → **`regs` hub** → Modbus pipeline, with the
cross-cutting `main` super-loop, `board` safety services and `sensors.h`
build-variant gating, and the `avg` / `circmean` / `persist` satellites off
the hub. Solid = runtime data/calls, dotted = compile-time or control.

### 7.2 Super-loop sequence — one cooperative iteration (see §2, §3)

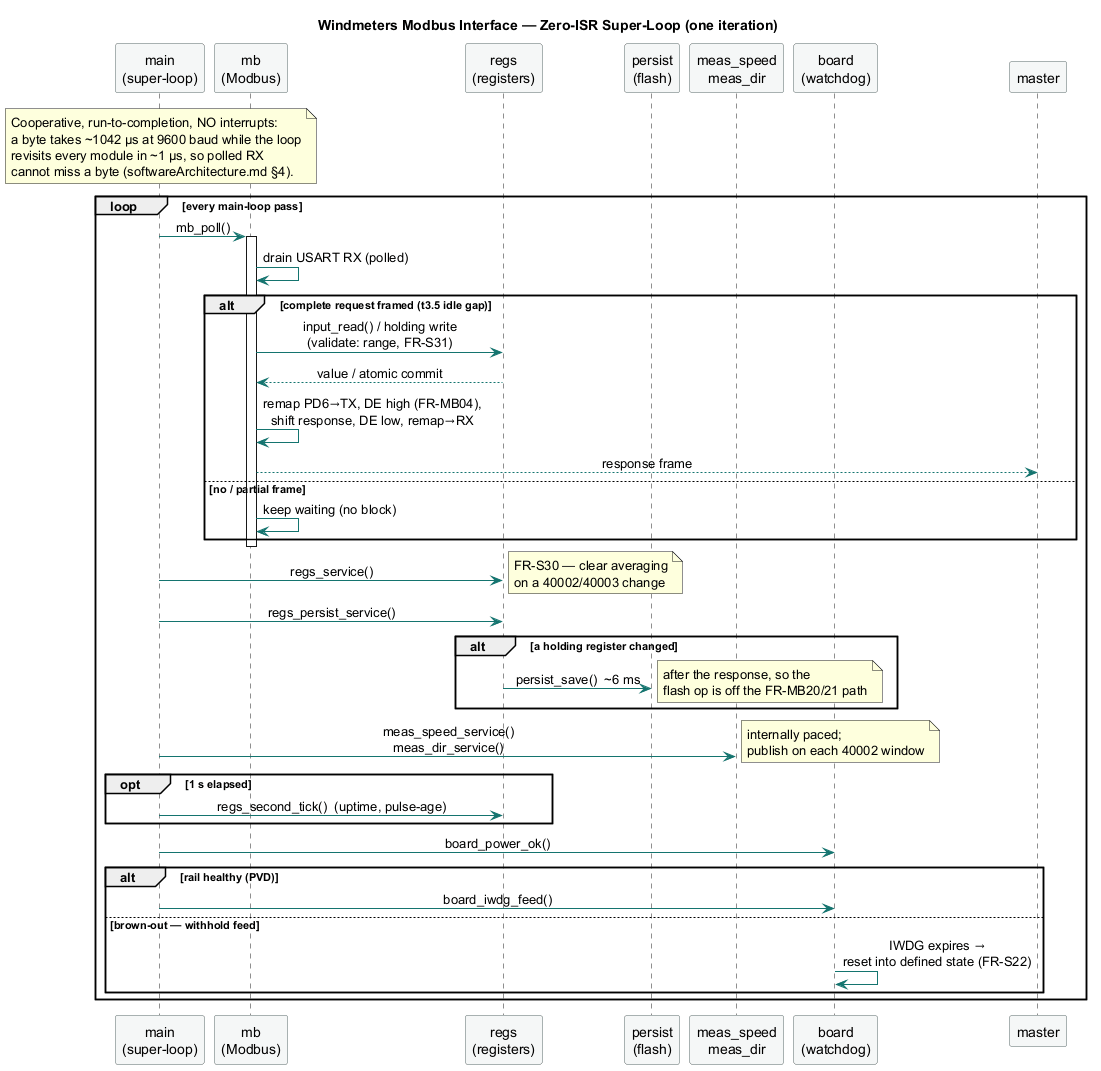
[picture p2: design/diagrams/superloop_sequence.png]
Super-loop sequence diagram


Source: [`diagrams/superloop_sequence.puml`](diagrams/superloop_sequence.puml).
One pass of the zero-ISR loop: `mb_poll` (polled RX with the request/response
handled in-line) → `regs_service` → `regs_persist_service` (flash only on a
change, and only after the response) → the measurement services → the
PVD-gated watchdog feed. No interrupts, so there is no concurrency surface.

### 7.3 Modbus RTU line discipline — state machine (see §3)

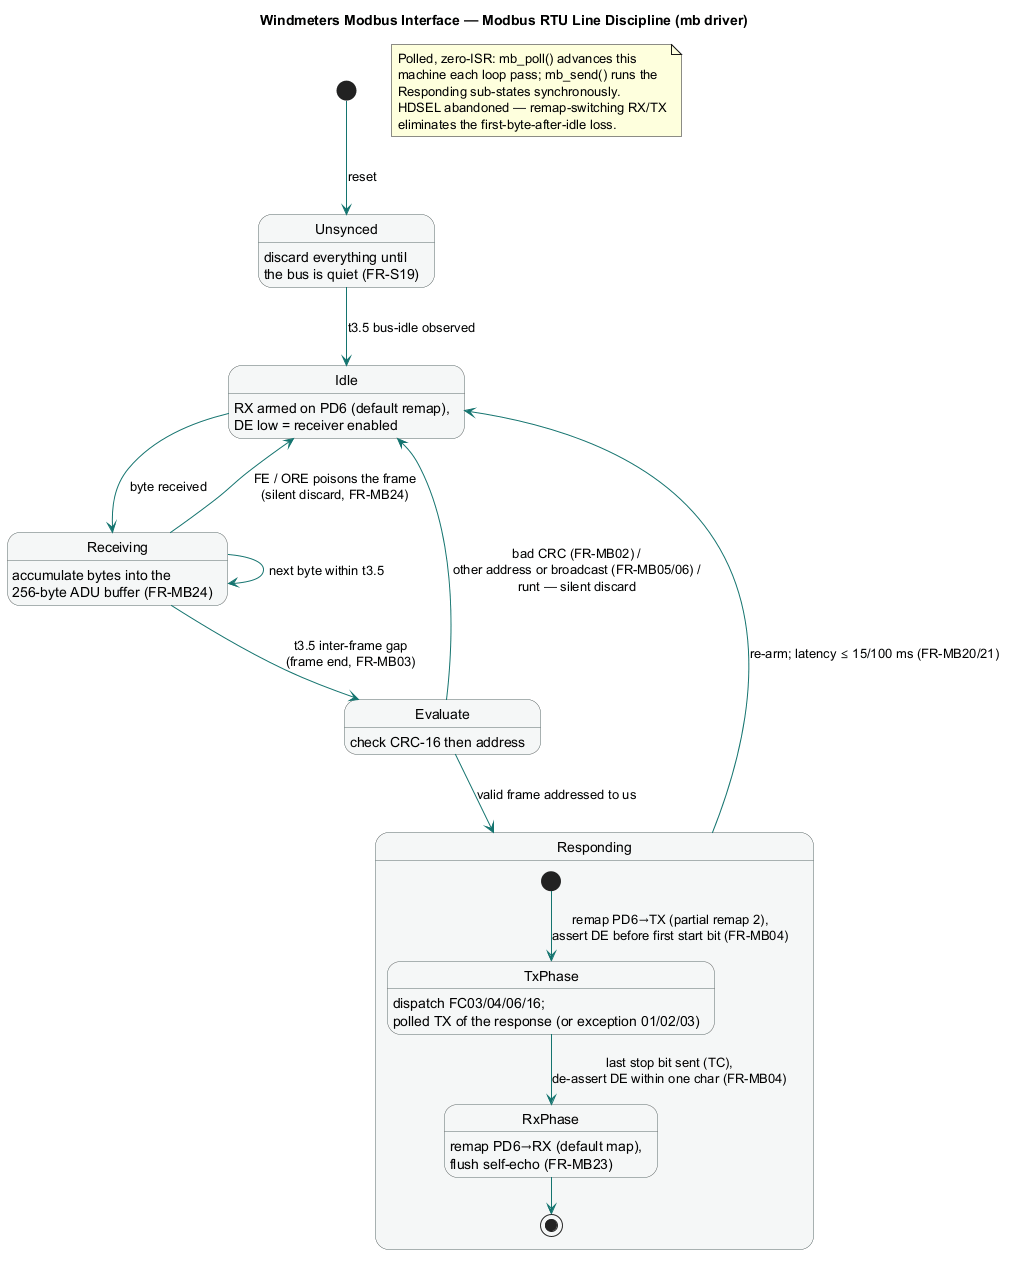
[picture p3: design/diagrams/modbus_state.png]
Modbus RTU line-discipline state machine


Source: [`diagrams/modbus_state.puml`](diagrams/modbus_state.puml). The
remap-switching RX/TX discipline: unsynced → idle → receiving → evaluate →
`Responding` (Tx-phase / Rx-phase composite) → idle. HDSEL was abandoned per
the amendment in §1; DE timing and t3.5 gaps carry their FR IDs on the
transitions.

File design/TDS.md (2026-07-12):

# Technical Design Specification — Windmeters Modbus Interface

| Field | Value |
|---|---|
| Document | Technical Design Specification |
| Project | `windmeters-modbus-interface` (DUT firmware) |
| Version | 0.9 (draft — §2 Modbus, §3 Software, §4 Hardware, §5 NFRs; v0.6 removed the device-address register (address is hardware-configured only); v0.7 added FR-S39 holding-register persistence and the combined build variant; v0.8 added runtime+persistent anemometer calibration (FR-S40, 40005/40006); v0.9 promotes the as-built hardware design from the KiCad PCB into the new §4 and closes/narrows the §6 open items) |
| Date | 2026-07-12 |
| Status | Draft. Hardware, power, and calibration derivation are now captured in §4 from the as-built KiCad PCB (`hardware/KiCad/`); residual open items are tracked in §6. |
| Related docs | `hardware/KiCad/windmeter-modbus-interface.kicad_{sch,pcb}` (as-built PCB — source for §4); `design/scratchBook.md` (original register-map/hardware/calibration reasoning, superseded by §2/§4 where they overlap); sibling `windmeters-modbus-interface-tester` repo's `design/progress.md` §7 and `design/whatsNext.md` §3.2 (bench evidence cited in §2) |

---

## 1. Purpose and scope

`scratchBook.md` is working notes: what the registers mean, how the
hardware is wired, how calibration is derived. This document holds the
things the firmware **must** do, each with a testable pass/fail —
including the failure paths (unsupported function codes, unimplemented
registers, out-of-range writes) that otherwise get decided implicitly,
one `if` statement at a time, while `software/firmware/src/main.c` is
still scaffolding.

Requirements are seeded from two sources: the Modbus RTU specification,
and bench observations made testing a real commercial slave (an FG6485A
humidity/temperature sensor) with the `windmeters-modbus-interface-tester`
tool. Version 0.4 additionally incorporates a systematic six-lens gap
audit (firmware lifecycle, protocol completeness, measurement data path,
configuration/persistence, diagnostics, NFRs/testability) that confirmed
38 gaps, including three internal contradictions now resolved (see
FR-MB16, FR-MB26, FR-S21).

Key design decisions fixed in this version:

- Holding registers persisted across reset in flash-emulated non-volatile storage (FR-S39); §2.8 defaults apply only on first boot / erased store (FR-S21).
- Device address is hardware-configured only (build define + PC4 solder jumper); there is no address register — see FR-S03/FR-MB07.
- Exception 04 never emitted; faults handled by watchdog and defined register values — see FR-MB29.
- Hardware captured as-built from the KiCad PCB (§4): one unmodified 2-layer board serves all three build variants (FR-S02), 24 V passive PoE, a MAX3485 transceiver, and RJ14 sensor jacks.

---

## 2. Modbus requirements

### 2.1 Physical layer, framing, and receiver robustness

| ID | Priority | Requirement | Pass/Fail criterion |
|----|---|---|---|
| FR-MB01 | Must | The firmware shall communicate using Modbus RTU framing at 9600 baud, 8 data bits, no parity, 1 stop bit (8N1). | Connect a Modbus analyser or the tester at 9600 8N1; all frames are decoded without framing errors. |
| FR-MB02 | Must | Frames with an invalid CRC-16 shall be silently discarded. No response shall be sent. | Send a frame with a deliberately corrupted CRC; confirm no reply within 200 ms. |
| FR-MB03 | Must | The firmware shall detect the inter-frame gap (3.5 character times) as the frame boundary. One character time is defined as 11 bits per the Modbus RTU specification (11/9600 s ≈ 1.15 ms), so 3.5 character times ≈ 4.0 ms at 9600 baud; this definition applies wherever this document says "character time". A new frame starts after this silence. | Two back-to-back valid requests separated by ≥5 ms are both processed correctly. Send the first 4 bytes of a valid request, pause ≥5 ms, then send the remaining bytes: no response of any kind within 200 ms; an immediately following complete valid request receives a correct response, proving the receiver state machine recovered. |
| FR-MB04 | Must | The RS-485 driver-enable line (DE/RE on PC2) shall be asserted before the first transmitted byte and de-asserted after the last transmitted byte, within one character time (≈1.15 ms at 9600 baud). | Scope DE/RE and TX lines: DE asserts before TX start bit; DE de-asserts within one character time after the last stop bit. |
| FR-MB23 | Must | While the firmware is transmitting (DE asserted), any bytes appearing on the USART receiver shall be discarded and shall not be evaluated as an incoming frame. (The MAX3485 RO and DI are tied on the shared PD6 data node, §4.3; RO is high-Z while DE is asserted, and the firmware uses a remap-switching line discipline — USART1 RX native on PD6, TX remapped onto PD6 only for the response — rather than HDSEL, which bench testing showed intermittently swallows the first byte after bus idle.) Frame reception shall re-arm only after DE is de-asserted and a 3.5-character idle time has elapsed. | Bus-analyser capture: send one valid FC04 request and confirm exactly one response frame is transmitted and the bus then stays idle — no self-triggered frame within 500 ms. Repeat 100 times back-to-back with zero spurious frames. |
| FR-MB24 | Must | On any USART receive error (overrun, framing, noise) or on receiving more bytes without a 3.5-character gap than the receive buffer holds (the buffer shall accept frames up to the 256-byte Modbus RTU ADU maximum), the firmware shall discard the frame in progress, clear the error condition, and resynchronise on the next ≥3.5-character idle gap. No buffer overflow and no receiver lockup shall occur. | Transmit continuous pseudo-random bytes at 9600 baud with no idle gaps for 60 s, then one valid FC04 request: a valid response arrives within the FR-MB20 budget; repeat 10 times with 100% success. Send a 400-byte "frame" followed by a ≥5 ms gap and a valid request: no response to the burst, valid response to the request; 20 repetitions without failure or reset. |
| FR-MB25 | Must | All 16-bit register values and 16-bit address/quantity fields in request and response PDUs shall be transmitted big-endian (high byte first). The CRC-16 field shall be transmitted low byte first, high byte second, per the Modbus RTU specification. | With wind direction held at a known 90.0° (register value 900 = 0x0384), an FC04 read of raw 0x0000 returns data bytes 0x03 then 0x84 in that order, decoded as 900 by the tester with no byte-swap option. The final two bytes of every captured frame validate as CRC low-byte-first. |

### 2.2 Addressing

| ID | Priority | Requirement | Pass/Fail criterion |
|----|---|---|---|
| FR-MB05 | Must | The firmware shall respond only to requests addressed to its currently active Modbus address. Requests addressed to any other unicast address shall be silently ignored. | With the DUT as the only slave on the bus, send a valid FC04 request to address 247 (never assigned in this product family per FR-S03): no reply within 200 ms. Send the same request to the DUT's own address: valid reply. |
| FR-MB06 | Must | Broadcast requests (address 0) shall be silently ignored — not executed, no response sent. *Deliberate deviation from Modbus-over-Serial-Line V1.02 §2.2, which requires slaves to execute broadcast writes. Rationale: broadcast execution of configuration writes risks unintended fleet-wide reconfiguration and offers no benefit given jumper-derived addressing (FR-S03). This deviation shall be stated in user-facing register-map documentation.* | Send a valid FC06 write to address 0; confirm no reply within 200 ms and no register change on follow-up read. |
| FR-MB07 | Must | The device address shall be latched at startup per FR-S03 (the single normative source of the address table) and shall not change until the next reset. There is no Modbus-accessible address register. | Wind-speed build: power cycle with solder jumper open → device responds at 30 and not at 35; with jumper bridged → responds at 35 and not at 30. Wind-direction build: same test with 31/36. A jumper change mid-cycle has no effect until the next reset. |
| FR-MB26 | — | **Withdrawn (v0.6).** The device-address holding register was removed from the map: the address is hardware-configured only (build define + PC4 solder jumper, FR-S03) and cannot be read or changed over Modbus. A write to the (now unmapped) former address falls under FR-MB15. | — |

### 2.3 Supported function codes

| ID | Priority | Requirement | Pass/Fail criterion |
|----|---|---|---|
| FR-MB08 | Must | FC04 (Read Input Registers) shall be supported for all input register addresses in §2.7. | FC04 request for each register in §2.7 returns a valid response with correct byte count and data. |
| FR-MB09 | Must | FC03 (Read Holding Registers) shall be supported for all holding register addresses in §2.8. | FC03 request for each register in §2.8 returns a valid response with correct byte count and data. |
| FR-MB10 | Must | FC06 (Write Single Register) shall be supported for all holding register addresses. | FC06 write of a valid value to each holding register is accepted; follow-up FC03 read confirms the new value. |
| FR-MB11 | Must | FC16 (Write Multiple Registers) shall be supported for holding registers. | FC16 write of valid values to two consecutive holding registers is accepted; follow-up reads confirm both values changed. |
| FR-MB12 | Must | Any function code other than FC03, FC04, FC06, FC16 shall be rejected with exception 01 (Illegal Function). | Send FC01, FC02, FC05; confirm exception 01 response for each. Bench evidence: the FG6485A's non-standard exception code (0x81 with code 129) caused the tester decoder to fall back to "unknown" — standard code 01 avoids this. |
| FR-MB30 | Must | The normal (success) response to FC06 shall be a byte-exact echo of the request frame. The normal response to FC16 shall contain: slave address, function code 0x10, starting address (2 bytes), quantity of registers written (2 bytes), CRC — not the register data. | Capture request and response for FC06 write 40001 = 100: the two frames are byte-identical. For an FC16 write of 2 registers at raw 0x0001: the response PDU after the function code is exactly 0x00 0x01 0x00 0x02. |

### 2.4 Register access rules

| ID | Priority | Requirement | Pass/Fail criterion |
|----|---|---|---|
| FR-MB13 | Must | A read request for any register address not listed in §2.7 or §2.8 shall return exception 02 (Illegal Data Address). | FC04 or FC03 request for raw address 0x0020; confirm exception 02. |
| FR-MB14 | Must | A multi-register read (FC03/FC04) whose range spans at least one unimplemented address shall return exception 02 for the entire request. No partial data shall be returned. | FC04 request starting at the last valid input address with count 2; confirm exception 02, not partial data. |
| FR-MB15 | Must | A write to an unimplemented holding register address shall return exception 02. | FC06 write to raw holding address 0x0020; confirm exception 02 and no side effect. |
| FR-MB16 | — | **Withdrawn (v0.4).** Modbus has one address space per function code: FC06/FC16 by definition address the holding-register space (§2.8) exclusively; input registers (§2.7) are reachable only via FC04 and are read-only by construction. There is no wire-level "write to an input register" to reject. A write whose raw address is not listed in §2.8 is handled by FR-MB15. | *Non-normative regression note (owned by FR-MB10):* FC06 write of value 32 to raw 0x0000 (direction offset, valid range 0–3599) returns a normal response and follow-up FC03 confirms the value; FC04 read of raw 0x0000 still returns the measurement, unmodified by that write. Withdrawn IDs are excluded from NFR-TST01. |
| FR-MB27 | Must | Every firmware build shall implement the §2.7/§2.8 register map: the single-sensor builds map raw 0x0000–0x000B (12 input registers), the combined build additionally maps 30013 (§2.7). Input registers whose sensor is not present in the active build shall read 0 (except raw 0x0004, which reports the build-specific diagnostic per §2.7). Configuration holding registers shall accept and store range-valid writes on every build — with no measurement effect where the sensor is absent — and read back the stored value. No mapped register shall return exception 02 on any build. | On a wind-speed build, FC04 read of raw 0x0000–0x0004 quantity 5 returns a normal response with 0x0000 and 0x0002 equal to 0. On a wind-direction build the same read succeeds with 0x0001 and 0x0003 equal to 0. FC06 write of 100 to 40001 (direction offset) on a wind-speed build is accepted and reads back 100. On a combined build both sensors' registers are live and FC04 of 0x000C (30013) succeeds. |
| FR-MB28 | Must | FC03/FC04 requests with quantity = 0 or > 125 shall return exception 03 (Illegal Data Value). FC16 requests with quantity = 0, quantity > 123, or a byte-count field not equal to 2 × quantity shall return exception 03 and shall modify no register. Quantity validation shall be performed before address validation. | FC04 at raw 0x0000 with quantity 0 returns exception 03 (not 02, not an empty data frame) within 200 ms. FC03 with quantity 126 returns exception 03. FC16 to raw 0x0001 with quantity 2 but byte count 5 returns exception 03 and follow-up reads show both registers unchanged. |

### 2.5 Exception handling

| ID | Priority | Requirement | Pass/Fail criterion |
|----|---|---|---|
| FR-MB17 | Must | For any addressed request the firmware cannot fulfil, a well-formed Modbus exception response shall be returned. The firmware shall never stay silent on a valid addressed request. | Send FC04 for an unimplemented address; confirm a response arrives within 200 ms. Bench evidence: the tester's bus scanner detects a device only because it exception-replies — a silent device is invisible to `bus_scan_did_respond()`. |
| FR-MB18 | Must | Exception responses shall use only the standard Modbus exception codes: 01 Illegal Function, 02 Illegal Data Address, 03 Illegal Data Value. No vendor-specific codes shall be used. (Code 04 is standard but deliberately never emitted — FR-MB29.) | For each exception path (FR-MB12/13/15/19/28), confirm the exception byte is one of 01/02/03 and is decoded correctly by the tester's `exception_name` field. Bench evidence: FG6485A returned code 129 (non-standard); the tester decoder fell back to "unknown". |
| FR-MB19 | Must | A write (FC06/FC16) with a value outside the valid range defined in §2.8 shall return exception 03 (Illegal Data Value). The register shall be left unchanged. The firmware shall not clamp the value to the nearest valid bound, and shall not echo success while discarding the value. | Write direction offset (40001) = 4000 (out of range); confirm exception 03; follow-up read shows the register unchanged (not clamped to 3599). Bench evidence (INT-06): FG6485A echoed success for an out-of-range write but silently discarded the value — indistinguishable from a real write without an unprompted read-back. |
| FR-MB22 | Must | An FC16 write shall be atomic: if any value in the request is outside its valid range (including the cross-register constraint FR-S31), the entire request shall be rejected with exception 03 and no register in the range shall be modified. | FC16 write to 40001–40002 with a valid offset (e.g. 100) and an invalid window (e.g. 65000); confirm exception 03 and follow-up reads show both registers unchanged — including the one whose value was valid. |
| FR-MB29 | Should | The firmware shall never emit exception 04 (Slave Device Failure). Internal faults are handled by watchdog reset (FR-S20) and defined register values (FR-S21/FR-S29) instead. Exceptions shall be emitted only per the enumerated triggers: 01 per FR-MB12; 02 per FR-MB13/14/15; 03 per FR-MB19/22/28 and FR-S31. | Code review confirms no code path emits exception 04. Fault injection of documented conditions (bad function code, bad address, bad value, bad quantity) produces only the enumerated codes. |

### 2.6 Response timing

| ID | Priority | Requirement | Pass/Fail criterion |
|----|---|---|---|
| FR-MB20 | Must | The firmware shall transmit its response within 100 ms of receiving the last byte of a valid request. | Measure time from last RX byte to first TX byte using the tester's raw frame timestamps; confirm ≤100 ms for FC03, FC04, FC06, and FC16 requests. |
| FR-MB21 | Should | Under default configuration, at least 95% of responses shall start within 15 ms of the last request byte. | Issue 1,000 FC04 requests at 50 ms spacing with default configuration: at least 95% of responses start within 15 ms of the last request byte, and 100% within the FR-MB20 limit of 100 ms, measured from the tester's raw frame timestamps. |

### 2.7 Input register map (FC04, read-only)

Measurement registers 30001–30005 and 30012 read 0 from reset until the first measurement window completes (FR-S23). Identification, status, uptime, counter, and time-since-pulse registers (30006–30011) are valid immediately after reset. ● = active on this build; ○ = present but reads 0 on this build (FR-MB27); — = not mapped on this build (FC04 past the map edge returns exception 02, FR-MB13). The map edge is 0x000C (12 registers) on the single-sensor builds and 0x000D (13 registers) on the combined build, which adds 30013.

| Raw | Modicon # | Description | Unit | Range | Speed | Direction | Combined |
|-----|---|---|---|---|---|---|---|
| `0x0000` | 30001 | Wind direction, instantaneous | 0.1° | 0–3599; 65535 = sensor fault (FR-S38) | ○ | ● | ● |
| `0x0001` | 30002 | Wind speed, instantaneous | 0.1 m/s | 0–65535 | ● | ○ | ● |
| `0x0002` | 30003 | Wind direction, averaged | 0.1° | 0–3599; 65535 = sensor fault (FR-S38) | ○ | ● | ● |
| `0x0003` | 30004 | Wind speed, averaged | 0.1 m/s | 0–65535 | ● | ○ | ● |
| `0x0004` | 30005 | Raw sensor diagnostic | build-specific | speed & combined: pulse count last window (0–65535); direction: last raw 10-bit ADC conversion (0–1023) | ● | ● | ● |
| `0x0005` | 30006 | Status flags (normative definition: FR-S33) | bitfield | bit 0 = no completed window yet; bit 1 = averaging accumulator not filled; bit 2 = direction sensor fault; bits 3–15 = 0 | ● | ● | ● |
| `0x0006` | 30007 | Identification | — | high byte = build type (0x01 speed, 0x02 direction, 0x03 combined); low byte = firmware version (FR-S32) | ● | ● | ● |
| `0x0007` | 30008 | Uptime since reset | s | 0–65535, saturating (FR-S34) | ● | ● | ● |
| `0x0008` | 30009 | Bus CRC error count | — | 0–65535, wrapping (FR-S35) | ● | ● | ● |
| `0x0009` | 30010 | Served request count | — | 0–65535, wrapping (FR-S35) | ● | ● | ● |
| `0x000A` | 30011 | Seconds since last pulse | s | 0–65535, clamped (FR-S36) | ● | ○ | ● |
| `0x000B` | 30012 | Gust: max window speed in current averaging window | 0.1 m/s | 0–65535 (FR-S37) | ● | ○ | ● |
| `0x000C` | 30013 | Wind direction, raw 10-bit ADC — combined build only (on single-direction builds this diagnostic is at 30005) | — | 0–1023 | — | — | ● |

### 2.8 Holding register map (FC03/FC06/FC16, read-write)

All holding registers persist across reset in non-volatile storage (FR-S39); the Default column is the value on first boot / when the store is blank or corrupt (FR-S21). Writes outside the valid range are rejected per FR-MB19/FR-MB22. A cross-register constraint between 40003 and 40004 is defined and enforced solely by FR-S31. Registers 40005/40006 are the anemometer calibration (FR-S40) — they affect only the speed path (inert on a direction-only build, per FR-MB27).

| Raw | Modicon # | Description | Unit | Valid range | Default |
|-----|---|---|---|---|---|
| `0x0000` | 40001 | Wind direction calibration offset | 0.1° | 0–3599 | 0 |
| `0x0001` | 40002 | Measurement window duration | ms | 100–60000 | 1000 |
| `0x0002` | 40003 | Averaging window | s | 1–600, subject to FR-S31 | 10 |
| `0x0003` | 40004 | Low-speed cut-off threshold | 0.1 m/s | 0–50 | 4 |
| `0x0004` | 40005 | Anemometer calibration factor C (FR-S40) | 0.001 m/rotation | 1–6553 | 980 |
| `0x0005` | 40006 | Anemometer pulses per rotation (FR-S40) | pulses/rot | 1–1000 | 1 |

The device address is not a register: it is hardware-configured per FR-S03 and unreachable over Modbus (FR-MB07/FR-MB26).

---

## 3. Software requirements

### 3.1 Build configuration and startup

| ID | Priority | Requirement | Pass/Fail criterion |
|----|---|---|---|
| FR-S01 | Must | The firmware shall be selectable at compile time for wind speed, wind direction, or combined (both sensors, one slave) mode via a pre-processor define. | Build with `SENSOR_WIND_SPEED` produces a wind-speed binary, `SENSOR_WIND_DIRECTION` a wind-direction binary, and `SENSOR_WIND_COMBINED` a combined binary. All build without error from the same source tree. |
| FR-S02 | Must | A single hardware PCB shall support both sensor types without modification — individually (speed or direction build) or together (combined build). | Flash each release binary onto one unmodified PCB in turn; each build passes its full §2/§3 acceptance suite on that board. |
| FR-S03 | Must | The power-on Modbus device address shall be determined at startup by combining the firmware build type with the state of the solder jumper on PC4. This table is the single normative source of the address assignment: wind speed — jumper open = 30, bridged = 35; wind direction — jumper open = 31, bridged = 36; combined — jumper open = 32, bridged = 37. There is no address register; the address cannot be changed at runtime (FR-MB07). | Reading PC4 GPIO at startup selects the address per the table; the device responds only on that address after power-on (FR-MB07's criterion). |
| FR-S18 | Must | Initialization shall complete in this order before the main loop starts: (1) PC2 (DE/RE) configured as output driven low — receiver enabled, driver disabled — as the first GPIO action after reset; (2) PC4 read and the Modbus address latched; (3) sensor front-end ready — direction build: ADC self-calibration executed before the first conversion; speed build: TIM2 counter cleared at the instant the first measurement window opens; (4) USART1 receiver enabled last. | (a) Direction build: the first non-zero value after power-on at a fixed pot angle is within the FR-S11 tolerance, with no settling sequence of wrong values. (b) Speed build: with pulses applied from before power-on, the first completed window's 30005 equals rate × window ±1 pulse. (c) A valid request sent repeatedly from power-on is never answered from a wrong address. |
| FR-S19 | Must | The firmware shall never transmit on the bus except in response to a valid addressed request (no boot banner, no test bytes). After any reset, received bytes shall be discarded until a bus-idle period of ≥3.5 character times has been observed. | Scope PC2 and the bus across 20 power cycles while another master/slave pair actively exchanges frames: DE never asserts except to answer a valid request to the DUT, and a DUT reset injected mid-frame of third-party traffic produces no response to that partial frame. |

### 3.2 Reliability and lifecycle

| ID | Priority | Requirement | Pass/Fail criterion |
|----|---|---|---|
| FR-S20 | Must | The independent watchdog (IWDG) shall be enabled before the main loop starts, with a timeout between 100 ms and 2 s, refreshed only from the main loop after both the Modbus service and the measurement service have run — never from an interrupt handler. | (a) Via a debug-build hook that enters an infinite loop, confirm the device resumes answering a valid FC04 within 3 s without a power cycle. (b) 24 h of continuous polling under normal operation triggers zero watchdog resets. |
| FR-S21 | Must | After any reset (power-on, brown-out, watchdog, software), the firmware shall enter a defined state: holding registers restored to their last persisted values (FR-S39), or to §2.8's Default column when the persistent store is blank/corrupt; all measurement accumulators cleared. No Modbus-commanded reset shall exist; power cycling is the only reset a master or installer can invoke. | Trigger each reset source in turn (power cycle, watchdog hook, software reset): after each, the device responds at the jumper-derived address within 1 s, FC03 of raw 0x0000–0x0005 returns the last committed values (FR-S39), and all accumulators are cleared (status bits 0/1 set). On a device with an erased store the same read returns exactly the §2.8 Default column. |
| FR-S39 | Must | The six holding registers (40001–40006) shall persist across every reset and power-loss in on-chip non-volatile storage. On a write that *changes* a holding value (FC06/FC16, after it passes FR-MB19/FR-MB22/FR-S31 validation and the Modbus response has been transmitted), the firmware shall commit the whole holding set so a subsequent reset restores it (superseding the §2.8 defaults, per FR-S21). The commit shall be power-loss atomic — a reset at any point during a commit leaves the previously committed set intact, never a partial/corrupt configuration — and shall fall back to the §2.8 compile-time defaults when no valid record exists (first boot / erased store). Unchanged writes shall not wear the store. | Write non-default 40001–40006, trigger a watchdog reset, confirm FC03 returns the written values (not §2.8 defaults) within 1 s. On an erased store the read returns the §2.8 defaults. Re-writing identical values causes no additional non-volatile write. Power interrupted mid-commit never yields a partial configuration (the prior committed set survives). |
| FR-S40 | Must | The anemometer calibration shall be runtime-configurable and persistent via two holding registers: 40005 = calibration factor C (0.001 m/rotation, 1–6553, default per FR-S25) and 40006 = pulses per rotation (1–1000, default 1), applied per FR-S06. A change to either shall clear the averaging accumulator (as FR-S30 does for 40002/40003) so the boxcar never mixes pre- and post-calibration values. The registers exist on every build (FR-MB27) but affect only the speed path; on a direction-only build they are inert. | At a fixed pulse rate, 30002 tracks 40005 and 1/40006 proportionally (e.g. 40006 = 4 quarters the reading vs 40006 = 1). Both survive a reset (FR-S39). Writing 40005 = 0/6554 or 40006 = 0/1001 is rejected with exception 03 (FR-MB19). Changing 40005 or 40006 re-asserts status bits 0/1 (FR-S33) until a fresh averaging span fills. |
| FR-S22 | Must | The device shall resume full normal operation (all §2 and §3 requirements) after any supply interruption or dip, without manual intervention. Brown-out protection (hardware POR plus PVD if needed) shall guarantee the MCU either operates correctly or is held in reset — no third state. | With a programmable supply, apply a dip matrix (3.3 V rail from 3.0 V to 0 V in 0.3 V steps; durations 1 ms to 10 s; 10 repetitions each): after every event the device answers a valid FC04 within 1 s of rail recovery with register contents equal to the defined post-reset state; zero hung/silent/garbage outcomes across the matrix. |
| FR-S23 | Must | Measurement input registers (30001–30005, 30012) shall be initialised to 0 at reset and shall read 0 until the first measurement window completes (status bit 0, FR-S33). From the first completed window until the averaging accumulator has filled once (status bit 1, FR-S33), averaged registers 30003/30004 shall be computed over only the samples actually acquired since reset — partial-window mean, no zero-padding and no stale seeding. | Apply a steady stimulus equivalent to 5.0 m/s from before power-on with window 1 s / averaging 10 s: every FC04 response before the first window boundary reads 0 in all measurement registers; at t = 3 s register 30004 reads 50 ±2 LSB, not ~15 (the zero-padded value). With 40003 = 600, reads at t = 30 s already reflect the stimulus. Over 20 power cycles no measurement register ever exceeds 60 (6.0 m/s) for the 5.0 m/s stimulus. |
| FR-S24 | Must | All register values returned in a single FC03/FC04 response shall form a coherent snapshot from one measurement update (interrupts briefly masked during the copy, or a double-buffer/sequence-counter scheme). In particular, on the speed build, 30002 and 30005 in the same response shall be consistent: 30002 equals the FR-S06 formula applied to that response's 30005, or 0 where the FR-S07 cut-off applies — never a mixture of two windows. | Drive PC1 with a pulse source alternating between two distinct rates synchronised to window boundaries; poll FC04 for 30001–30005 back-to-back for ≥1 hour (≥50,000 responses): the 30002/30005 consistency rule holds in 100% of responses and no response mixes values from two windows. |

*Interface assumption (non-normative): configuration persists across reset (FR-S39), so a master need not re-apply site configuration after a restart; 30008 (FR-S34) remains available to detect restarts.*

### 3.3 Wind speed measurement (speed build)

| ID | Priority | Requirement | Pass/Fail criterion |
|----|---|---|---|
| FR-S04 | Must | Wind speed shall be measured by counting rising edges of the anemometer reed-relay signal on PC1 using TIM2 in ETR external-clock counter mode. | Observed via 30005 (FR-S08): drive PC1 with a 50% duty square wave of f Hz for one window of W ms: 30005 reads round(f × W / 1000) ±1 — one count per cycle, proving a single edge polarity is counted (counting both edges would read double). |
| FR-S05 | Must | The measurement window duration shall be configurable via holding register 40002. Default per §2.8. | At a fixed pulse rate f: with 40002 = 500, 30005 reads round(f × 0.5) ±1; with 40002 = 2000, 30005 reads round(f × 2) ±1 (write take-effect semantics per FR-S30). At power-on the window is 1000 ms (§2.8 Default column). |
| FR-S06 | Must | Wind speed shall be computed in the millisecond domain as `v[0.1 m/s] = (count × C_scaled × 10) / (window_ms × pulses_per_rotation)`, where C_scaled is the calibration factor in units of 0.001 m/rotation (40005, FR-S25/FR-S40), pulses_per_rotation is the anemometer's pulses per revolution (40006, FR-S40, ≥ 1 so no divide-by-zero), and window_ms is the duration of the window in which the pulses were counted (the value 40002 had when that window opened). Results exceeding 65535 shall be clamped to 65535. | With 40003 = 10000 ms, 40006 = 1 and a pulse generator at known frequency f: 30002 equals round(f × C × 10) within ±(one pulse-count quantum for the window + 1 LSB) — i.e. ±2 LSB at a 10 s window. With C_scaled = 980, 40006 = 1, 40003 = 500 and a 10 Hz input: 30002 reads 98 ±2 LSB. Setting 40006 = 4 at the same input quarters the reading to 24–25 (no truncation loss — pulses_per_rotation divides the result, not the count). |
| FR-S07 | Must | When the computed wind speed is below the low-speed cut-off threshold (holding register 40004, default per §2.8), input register 30002 shall report 0. | At zero pulse count, 30002 reads 0. At pulse rates corresponding to speeds below the cut-off, 30002 reads 0. Above the cut-off, it reports the calculated value. |
| FR-S08 | Should | The raw pulse count for the last measurement window shall be available in input register 30005 for diagnostic purposes (speed build; see §2.7 for the direction build's use of this register). | Apply f Hz for one window of W ms: FC04 read of 30005 returns round(f × W / 1000) ±1. |
| FR-S25 | Must | The calibration factor C shall have a compile-time default set via a pre-processor define (integer fixed-point, 0.001 m/rotation, valid default range 1–6553 enforced by a static build-time assert, default 980 = r 0.07 m / η 0.45), documented in the source tree. That default seeds holding register 40005 (FR-S40); the running value is 40005, runtime-writable and persisted (FR-S39), so one firmware image calibrates any anemometer with no rebuild. | The compile-time default with `-D WS_C_SCALED=0` or `6554` fails to compile. On a running device, writing 40005 changes 30002 proportionally: at a fixed pulse rate, 40005 = 980 then 1100 give 30002 in the ratio 980:1100 ±1 LSB, and the new value survives a reset (FR-S39). |
| FR-S26 | Must | The wind-speed computation shall be evaluated in integer arithmetic with no intermediate overflow over the full input domain: count 0–65535, window 100–60000 ms, C_scaled 1–6553 (FR-S25). The maximum intermediate, 65535 × 6553 × 10 = 4,294,508,550, fits an unsigned 32-bit integer. | Unit-test the scaling function at the corners: (count = 65535, C_scaled = 6553, window = 100 ms) → 65535 (clamped per FR-S06), not a wrapped value; (count = 65535, C_scaled = 980, window = 60000 ms) → exactly 10704, computed through a >2²⁹ intermediate without wrap. (No corner with C_scaled = 6553 produces an unclamped result within the legal window range — unclamped requires window ≥ 65539 ms.) |
| FR-S27 | Should | If a TIM2 update (overflow) event occurs during a measurement window, the pulse count for that window shall saturate at 65535; register 30005 shall report 65535 and register 30002 shall report the speed computed from the saturated count per FR-S06 — never values derived from a modulo-65536 wrapped count. | Precondition: write 40003 = 60, then 40002 = 60000 (FR-S31 constraint). Inject a 2 kHz square wave downstream of the debounce RC for one full window (120,000 edges): 30005 reads 65535, not 54464. |

*Note (hardware, non-normative): the calibration derivation in §4.7 assumes 1 pulse per rotation; anemometers that emit a different number of pulses per revolution are handled at runtime via holding register 40006 (FR-S40, default 1), so no rebuild is required.*

### 3.4 Wind direction measurement (direction build)

| ID | Priority | Requirement | Pass/Fail criterion |
|----|---|---|---|
| FR-S09 | Must | Wind direction shall be measured by reading the potentiometer wiper voltage on PA2 using the ADC in 10-bit ratiometric mode referenced to VDD. No external reference shall be used. | Via input register 30005 (raw ADC diagnostic on the direction build, §2.7): wiper at each end stop reads ≤5 and ≥1018 respectively. |
| FR-S10 | Must | The ADC sample time shall be configured to ≥71 cycles to accommodate the 11 kΩ potentiometer source impedance. | Code review confirms the sample-time setting. Via 30005: 32 consecutive reads at a fixed mid position span ≤3 counts. |
| FR-S11 | Must | Wind direction shall be reported in input register 30001 in units of 0.1°, range 0–3599, where 0 = North, increasing clockwise (WMO convention), derived from the oversampled ADC value (FR-S28). Firmware accuracy — with the potentiometer replaced by a precision divider of ≤0.1% ratio accuracy — shall be ±10 LSB (±1.0°), covering quantization and INL. End-to-end accuracy including potentiometer linearity is a separate hardware/calibration item (target ±2°, §6). | At each of 5 known divider ratios, the reported value is within ±10 LSB of the expected angle; 100 reads over 60 s at a fixed ratio span ≤3 counts. |
| FR-S12 | Must | A calibration offset shall be applied to the reading before reporting. The offset shall be configurable via holding register 40001, in units of 0.1°, range 0–3599. | Writing offset value X to 40001: reported direction shifts by X × 0.1°, wrapping correctly at 360°/0°. |
| FR-S28 | Must | Each update of 30001 shall be derived from ≥16 ADC conversions (mean, or median with outlier rejection) at an update rate of ≥10 Hz, feeding the circular mean (FR-S14) at the same cadence. | Code review of the conversion scheme; the FR-S11 stability criterion (span ≤3 counts over 100 reads) passes. |
| FR-S29 | Must | The reported direction shall always lie in 0–3599 — with the sole exception of the FR-S38 fault value 65535; the value 3600 shall never be emitted at the wrap. | A full 360° sweep at 10 Hz logging produces no reading in 3600–65534; crossing the wrap shows a single step between high (359x) and low (000x) values. |
| FR-S38 | Must | A floating wiper (detectable by toggling the internal pull resistor on PA2 between two conversions and comparing readings) shall cause 30001 to hold the last valid direction for up to 2 s; if the condition persists >2 s, registers 30001 and 30003 shall report 65535 (sensor fault, §2.7) and status bit 2 (FR-S33) shall be set until valid readings resume. Floating-input samples shall be excluded from the circular mean. | Disconnecting the wiper at the RJ14 yields 65535 in both registers and status bit 2 within 3 s; recovery within 2 s of reconnection. Rotating slowly through any potentiometer dead zone shows the last valid value held, then a single step across the wrap. A 10-minute continuous-rotation sweep produces no false fault. |

### 3.5 Averaging

| ID | Priority | Requirement | Pass/Fail criterion |
|----|---|---|---|
| FR-S13 | Must | Averaged wind speed shall be reported in input register 30004 as the arithmetic mean of the measurement-window results falling within the last N seconds (boxcar, not exponential; exact or two-stage per FR-S31), N = value of 40003. Default N = 10 s (§2.8). | At a steady generator pulse rate, after a step change register 30004 is within ±2 LSB of register 30002's steady value no later than one averaging window plus one measurement window after the step (plus one aggregation block where FR-S31's two-stage boxcar is active, N > 64), and remains within ±2 LSB thereafter. |
| FR-S14 | Must | Averaged wind direction shall be reported in input register 30003 using a circular mean (sine/cosine method) over the same boxcar window (exact or two-stage per FR-S31), to correctly handle the 0°/360° wrap-around. | With the input alternating between 3500 (350.0°) and 100 (10.0°) at equal dwell, register 30003 reports a value in [3590–3599] ∪ [0–10] (0.0° ± 1.0°) after one full averaging window, and never reports a value in [1700–1900] (the 180° failure mode of a naive linear mean). |
| FR-S15 | — | **Withdrawn (v0.4).** Range enforcement for the averaging window (40003) is covered by FR-MB19/FR-MB22 against §2.8 (Must); a Should-priority duplicate made the same behaviour simultaneously waivable and mandatory. | Boundary test retained under FR-MB19: write 0 and 601 to 40003 → exception 03, register unchanged; write 1 and 600 → accepted (600 subject to FR-S31 given 40002). |
| FR-S30 | Must | A valid write to 40002 shall abort the in-progress measurement window; the partial count shall be discarded (not published to 30002/30005) and a new window of the new duration shall start immediately. A valid write to 40002 or 40003 shall clear the averaging accumulator; 30003/30004 shall retain their last published values until the first new window completes, then follow the partial-window-mean rule (FR-S23). Status bits 0 and 1 (FR-S33) shall re-assert accordingly: bit 0 until the restarted window completes, bit 1 until the cleared accumulator refills. | At a constant pulse rate, write 40002 = 5000 mid-window: the next change of 30005 occurs no sooner than 5000 ms after the write and corresponds to a full 5000 ms window ±2% (FR-S17); status bit 0 is set from the write until that window completes. Write 40003 = 5 mid-average: bit 1 sets, 30004 never publishes a value outside the interval between its pre-write value and 30002, and reads 30002 ±1 LSB within 5 s, after which bit 1 clears. |
| FR-S31 | Must | The firmware shall enforce (40003 × 1000) ≥ 40002 at all times: any FC06/FC16 write violating this shall be rejected with exception 03 and leave the register(s) unchanged (respecting FR-MB22 atomicity). This row is the single normative source of the constraint. The average shall span N = floor((40003 × 1000) / 40002) completed windows (N ≥ 1). For N ≤ 64 the boxcar shall be exact; for N > 64 a two-stage boxcar is permitted: consecutive windows aggregated into blocks of ⌈N/64⌉ windows (block mean for speed, block sine/cosine sums for direction, block maximum for gust), the published value computed over the stored blocks, with an effective span within ±one block of N windows. This bounds storage at ≤64 entries per quantity, satisfiable at the worst-case ratio N = 6000 within NFR-RES01's RAM ceiling. | Precondition for the first vector: write 40003 = 60, then 40002 = 60000. FC06 write 40003 = 30 then returns exception 03 and 40003 is unchanged; write 40003 = 60 is accepted. With 40002 = 100 and 40003 = 600 at a steady pulse rate, the device meets FR-MB20 timing for ≥10 minutes and 30004 settles to 30002 ±1 LSB. |

### 3.6 Clock and timing

| ID | Priority | Requirement | Pass/Fail criterion |
|----|---|---|---|
| FR-S16 | Must | The firmware shall operate from the CH32V003 internal 48 MHz RC oscillator (HSI). No external crystal is required. | With no external crystal fitted: 10,000 Modbus request/response cycles at 9600 baud complete with zero framing/CRC errors, and the FR-S17 room-temperature window-timing criterion passes. |
| FR-S17 | Must | The measurement window timing error shall not exceed ±2% relative to the configured window duration at 25 ±10 °C, and ±3% over the full NFR-ENV01 temperature range (HSI drift dominates outside room temperature). | Window measured with an external timer: error ≤ ±2% over 10 consecutive windows at room temperature; ≤ ±3% at the NFR-ENV01 chamber extremes. |

### 3.7 Diagnostics and identification

| ID | Priority | Requirement | Pass/Fail criterion |
|----|---|---|---|
| FR-S32 | Must | Input register 30007 shall identify the device: high byte = build type (0x01 wind speed, 0x02 wind direction, 0x03 combined), fixed at compile time, independent of PC4; low byte = firmware version, incremented per release. | FC04 read returns 0x01vv on a wind-speed binary, 0x02vv on a wind-direction binary, and 0x03vv on a combined binary built from the same source commit. The value is identical with jumper open/bridged. The version byte matches the release records for the flashed binary. |
| FR-S33 | Must | Input register 30006 shall report status flags — this row is the single normative bitfield definition: bit 0 = no completed measurement window since reset or since the last 40002 write (FR-S23/FR-S30); bit 1 = averaging accumulator not yet filled since reset or since the last 40002/40003 write (FR-S23/FR-S30); bit 2 = direction sensor fault (FR-S38; direction build only, always 0 on the speed build); bits 3–15 = 0. | At power-on bits 0 and 1 are set; bit 0 clears after the first window, bit 1 after one full averaging window; both re-assert after a 40002 write per FR-S30's criterion. Direction build: wiper disconnect sets bit 2 (FR-S38). Speed build: bit 2 remains 0 throughout. |
| FR-S34 | Must | Input register 30008 shall report whole seconds since the last reset, starting at 0 and saturating at 65535, allowing the master to detect restarts (value went backwards) and re-apply configuration (FR-S21). | A read shortly after power-on returns a low value; a later read has incremented consistently with FR-S17 timing accuracy; a watchdog reset via the test hook returns the register to 0. |
| FR-S35 | Should | Input registers 30009 and 30010 shall count, respectively, every frame discarded for invalid CRC-16 (regardless of address) and every request for which a normal or exception response was transmitted. Both reset to 0 at power-on and wrap at 65535. | After a power cycle both read 0. 100 valid FC04 requests increment 30010 by exactly 100 and leave 30009 unchanged. 20 corrupted-CRC frames increment 30009 by exactly 20 and 30010 by 0. |
| FR-S36 | Should | Input register 30011 (speed build) shall report elapsed whole seconds since the last rising edge on PC1 — initialised to 0 at reset and counting up until the first pulse — clamped at 65535 and reset to 0 on each pulse. Documented limitation: an open sensor wire, a stuck reed relay, and true calm are electrically indistinguishable (10 kΩ pull-up on PC1) — 30002 = 0 does not distinguish calm from a disconnected sensor; 30011 gives the master plausibility-check data. | Halt the pulse input: the register increments 1/s (±2%). Apply a single pulse: the next read returns ≤1. |
| FR-S37 | Should | Input register 30012 (speed build) shall report the maximum single-window instantaneous wind speed (0.1 m/s) observed within the current averaging window (rolling maximum, same window semantics as 30004; exact or two-stage per FR-S31). | Base pulse rate equivalent to 2.0 m/s with one 3 s burst equivalent to 8.0 m/s: within one measurement window of the burst the register reads 80 ±2 LSB while 30004 stays below 40; one full averaging window after the burst exits, it returns to 20 ±2 LSB. |

---

## 4. Hardware (as-built)

This section captures the interface board as built in the KiCad design
(`hardware/KiCad/windmeter-modbus-interface.kicad_{sch,pcb}`, KiCad 9;
schematic title block dated 2026-06-28), superseding the hardware notes in
`design/scratchBook.md`. The pin/net assignments in §4.2 are **normative** —
the firmware in §2/§3 targets them (FR-S03/S04/S09/S18, FR-MB04/FR-MB23);
component reference designators and values are as-built reference. One
unmodified 2-layer PCB serves all three build variants (FR-S02).

### 4.1 Architecture

A CH32V003J4M6 (U1) drives a MAX3485 (U2) RS-485 transceiver. Power is 24 V
passive PoE on the Ethernet spare pairs → a DB207 polarity-protection bridge
(B1) → an HLK-K7803-500R3 3.3 V regulator (P1). The bus is brought out on two
RJ45 jacks (J1, J3) for daisy-chaining; the two sensors connect on separate
RJ14 jacks (J4 anemometer, J5 wind-direction); a 3-pin header (J2) exposes
SWIO for the WCH-LinkE programmer. Termination, RS-485 pair selection, and
address selection are solder jumpers on the bottom side. Board: 2-layer,
1.6 mm, ≈ 67 × 92 mm, four Ø3.2 mm corner mounting holes.

### 4.2 MCU pin assignment (normative)

CH32V003J4M6, JEITA SOIC-8. The SOP-8 bonds out only six GPIO, and no USART1
remap places TX and RX on separate pins simultaneously — hence the
remap-switching data discipline on PD6 (FR-MB23), not HDSEL.

| Pin | Port | Net | Function | Firmware |
|-----|---|-----|---|---|
| 1 | PD6 | `MB-TX/RX` | Modbus data — USART1 RX native, TX remapped in for the response; to MAX3485 RO+DI | FR-MB23, FR-S19 |
| 2 | VSS | `GND` | Ground | — |
| 3 | PA2 | `ANALOG_IN` | Wind-direction ADC input (ch0, ratiometric); from J5 wiper | FR-S09/S10/S11 |
| 4 | VDD | `3V3` | +3.3 V supply | — |
| 5 | PC1 | `PULSE_IN` | Anemometer pulse — TIM2 ETR external-clock counter; from J4 via debounce network | FR-S04 |
| 6 | PC2 | `MB-RE/DE` | RS-485 driver enable (DE/RE) — to MAX3485; 10 k pull-down (R7) | FR-MB04, FR-S18 |
| 7 | PC4 | `ADDRESS` | Address-select jumper — 10 k pull-up (R4) + JP6 to GND | FR-S03 |
| 8 | PD1 | `SWIO` | Single-wire debug/flash — to J2; reserved, not used for I/O | — |

### 4.3 RS-485 interface

MAX3485 (U2), powered from 3.3 V.

- **Data**: RO and DI tied on net `MB-TX/RX` → PD6. RO is high-Z while DE is
  asserted, so the shared node is contention-free during transmit and needs
  no pull-up — the fail-safe idle level is set on the A/B bias, not the logic
  node.
- **Enable**: DE and RE tied on net `MB-RE/DE` → PC2, with a 10 kΩ pull-down
  (R7) holding the transceiver in receive while the MCU is in reset or being
  flashed.
- **Bus**: differential pair `RS485-A` / `RS485-B`, on both RJ45 jacks; the
  A/B-to-contact pairing is solder-jumper selectable (JP2/JP3 for J1,
  JP4/JP5 for J3).
- **Fail-safe bias**: R3 20 kΩ pulls A → 3.3 V, R2 20 kΩ pulls B → GND
  (idle = mark).
- **Termination**: R1 120 Ω across A–B, enabled by solder jumper JP1 (open by
  default).
- **Protection**: D1 SM712 TVS across A/B/GND.

### 4.4 Power supply

- **Input**: 24 V passive PoE on the Ethernet spare pairs — RJ45 pins 4 & 5 =
  +24 V, pins 7 & 8 = return — on both J1 and J3, so power passes down the
  daisy chain.
- **Polarity protection**: B1 DB207 bridge (used for reverse-polarity
  protection, not AC rectification) → regulator input; return = GND.
- **Regulator**: P1 HLK-K7803-500R3 (SIP-3, 3.3 V / 500 mA).
- **Filtering**: C3 100 µF electrolytic bulk on the regulator input; C4 4.7 µF
  electrolytic plus C1/C2 100 nF ceramic on the 3.3 V output. No inductor/LC
  filter is fitted.

### 4.5 Sensor front-ends

**Anemometer** (pulse) → PC1, via RJ14 **J4** (pin 1 = 3.3 V, pin 2 = pulse,
pin 3 = GND):

- Pulse path J4 pin 2 → R6 100 Ω series → `PULSE_IN`. On that node: R5 10 kΩ
  pull-up to 3.3 V (also the debounce pull-up — the reed relay pulls the node
  to GND when closed), C5 100 nF to GND (debounce, τ ≈ 1 ms), and D2 zener to
  GND (over-voltage clamp).
- The 10 kΩ pull-up is why an open sensor wire, a stuck-closed relay, and true
  calm are electrically indistinguishable (FR-S36).

**Wind direction** (potentiometer) → PA2, via RJ14 **J5** (pin 1 = 3.3 V,
pin 3 = GND, pin 4 = wiper):

- The potentiometer is in the sensor, not on the PCB, and is fed ratiometrically
  from the 3.3 V rail; the wiper drives `ANALOG_IN` → PA2 directly. The ADC is
  10-bit ratiometric to VDD with no external reference (FR-S09) and a 73-cycle
  sample time for the source impedance (FR-S10). There is no on-board RC filter
  on `ANALOG_IN` — ratiometric operation cancels rail ripple, and an external
  reference would break that cancellation.

### 4.6 Connectors

| Ref | Type | Purpose | Key pins |
|-----|---|---|---|
| J1, J3 | RJ45 (TE 215877-1) | Modbus daisy-chain | A/B on the signal contacts (jumper-paired); +24 V on 4 & 5, return on 7 & 8 |
| J4 | RJ14 (6P4C) | Anemometer | 1 = 3.3 V, 2 = pulse, 3 = GND |
| J5 | RJ14 (6P4C) | Wind direction | 1 = 3.3 V, 3 = GND, 4 = wiper |
| J2 | 1×3 header | Programming | GND / SWIO / 3.3 V |

Solder jumpers: JP1 termination; JP2–JP5 RS-485 pair select; JP6 address
select (all bottom-side).

### 4.7 Anemometer calibration derivation (C)

The calibration factor C (metres per rotation) converts pulse rate to wind
speed (FR-S06). It follows from cup-anemometer geometry:

C = 2πr / η

where r is the arm length from shaft centre to cup-body centre and η ≈ 0.45 is
the empirical efficiency of a small three-cup rotor (textbook 0.5; 0.40–0.50
across typical designs). For the reference sensor (r = 0.07 m, η = 0.45),
C ≈ 0.98 m/rotation → the compile-time default 980 (units of 0.001 m/rotation,
FR-S25). The η assumption carries ±10–12 % uncertainty versus a wind-tunnel
figure; where that matters, C is obtained empirically — hold the anemometer
beside a reference in the same airflow and solve C = v_reference /
pulses_per_second.

The compile-time default only **seeds** the running value: C lives in holding
register 40005 and the pulses-per-rotation divisor in 40006, both
runtime-writable and persisted (FR-S40/FR-S39), so one firmware image
calibrates any anemometer with no rebuild. The geometry above assumes one
pulse per rotation; other pulse counts are set in 40006 (default 1).

### 4.8 As-built notes and deviations

Captured from the KiCad design; where the as-built board differs from the
earlier `scratchBook.md` notes, the board governs:

- **Fail-safe bias designators** are the reverse of the notes (as-built: R3 →
  A/3.3 V, R2 → B/GND); the bias function is identical.
- **Power filtering** is C3 100 µF (input) + C4 4.7 µF (output) + 2 × 100 nF,
  not the notes' 10 µF/22 µF split; the 100 µF is the input bulk.
- **Two RJ14 sensor jacks** (J4 anemometer, J5 direction), not one; the
  anemometer enters on a jack, not a screw terminal.
- **No RC filter** on the wind-direction ADC input (the notes' 100 Ω + 10 µF is
  not fitted) — see §4.5.
- **D2 zener** is generic (`BZX84Cxx`) in the KiCad — pin the clamp voltage
  (nominally 3.3 V, BZX84-C3V3) on the manufacturing BOM.
- **Capacitor voltage ratings** are not carried in the KiCad Value fields;
  confirm on the BOM.
- The schematic title block reads "RS458" (typo for RS485) — cosmetic, fix on
  the next PCB revision.

---

## 5. Non-functional requirements

| ID | Priority | Requirement | Pass/Fail criterion |
|----|---|---|---|
| NFR-ENV01 | Must | All §2 and §3 requirements shall be met over an ambient temperature range of −25 °C to +70 °C. *(Range to be confirmed against the deployment site — §6; −40/+85 °C would require re-budgeting FR-S17.)* | In a climate chamber at both extremes: (a) 10,000 FC04 cycles at 9600 8N1 complete with zero framing/CRC errors; (b) the FR-S17 window measurement passes at its full-range tolerance. |
| NFR-RES01 | Should | Each release build variant shall occupy no more than 14,336 bytes of flash (87.5% of 16 KB); static RAM (.data + .bss) plus documented worst-case stack shall not exceed 1,792 bytes (87.5% of 2 KB). | The linker map of each release build shows totals at or below the ceilings; the build script prints the numbers and fails the build when exceeded. |
| NFR-BLD01 | Should | Both variants shall build from a clean checkout with a single documented command using a pinned toolchain (compiler name and exact version recorded in the repository). Two consecutive clean builds of the same commit shall produce bit-identical binaries. | Run the documented command twice from fresh clones of the same commit: SHA-256 of the two binaries per variant are identical; the recorded toolchain version matches the installed one. |
| NFR-TST01 | Should | Every protocol-level pass/fail criterion in §2 that is executable over the serial link shall be implemented as an automated test case in `windmeters-modbus-interface-tester`, and each build variant shall pass 100% of these cases before any release is tagged. Excepted (verified manually per release with bench instruments): FR-MB01 (analyser decode), FR-MB04 (scope timing), FR-MB23 (bus capture). Withdrawn IDs (FR-MB16, FR-MB26) are excluded. | The tester's run report for the release commit lists every non-excepted, active FR-MB ID with result PASS for each variant; any FAIL or missing ID blocks the release. |

---

## 6. Open items

Resolved items are kept briefly for traceability; only the residual work is
still open.

- **Response latency (FR-MB20/21) — CLOSED.** Measured with the real register
  code: median/worst 5.2 ms on the TTL rig, and 1000/1000 through the MAX3485
  at 4.07/4.12/4.17/4.44 ms (min/med/p99/max) — far under the 15 ms typical /
  100 ms hard budgets. The tester's 200 ms / 1-retry default keeps ample
  margin. (`software/hil/testReport.md`, P3-MB-LATENCY / R485-LAT-10D.)

- **NFR-ENV01 temperature range — NARROWED.** The assumed −25…+70 °C is
  covered by the as-built parts (CH32V003, MAX3485, HLK-K7803-500R3, DB207 are
  industrial-grade, typically rated to at least −40…+85 °C). Residual: confirm
  the electrolytic capacitors' temperature grade on the BOM (§4.8), confirm
  the range against the deployment site, and — only if −40/+85 °C is required
  — re-budget FR-S17 for HSI drift with chamber characterisation.

- **End-to-end direction accuracy — firmware CLOSED, sensor residual.** FR-S11
  firmware accuracy (±1.0°) is verified (−3.8 LSB against a precision
  divider). The total including the vane potentiometer's mechanical linearity
  (target ±2°) remains a sensor property, confirmed per installed vane. The C
  derivation has graduated into §4.7. Note: the as-built ADC input has no RC
  filter (§4.5) — the ratiometric supply and 73-cycle sample time carry the
  FR-S11 stability (verified span ≤ 3 counts); an RC filter is a future
  hardware option only if supply ripple ever proves limiting.

- **Hardware & calibration promotion — DONE.** The pin/net map, RS-485
  front-end, power chain, sensor front-ends, connectors, and the C derivation
  are now in §4 (as-built from the KiCad PCB). `scratchBook.md` is retained as
  historical reasoning.

- **Volatile-register coherence — CLOSED.** The 2026-07-03 review asked what a
  writable register is worth when its value evaporates on reset. The distilled
  rule — *operational knobs with universally valid defaults may be volatile;
  installation constants (offset), sensor constants (C, cut-off), and device
  identity (address) belong in hardware, compile-time defaults, or persistent
  storage* — was satisfied by making all six holding registers persistent
  (FR-S39, decision 2026-07-08) and the address hardware-only (v0.6). §2.8
  defaults now apply only on first boot / erased store.

- **Combined variant — SHIPPED; one strategic question open.** `wind_combined`
  (build 0x03, address 32/37) is implemented and validated
  (`design/integrationPlan.md` §10; 77/77 over RS-485 plus the raw suite and
  FR-S38). Undecided: whether the combined build eventually *replaces* the two
  single-sensor variants (its fault machinery already handles an absent
  sensor) — a product decision, not taken here.

- **Hardware BOM follow-ups (§4.8).** Pin the D2 zener clamp voltage
  (nominally BZX84-C3V3) and the capacitor voltage/temperature grades on the
  manufacturing BOM; fix the "RS458" schematic-title typo on the next PCB
  revision.

---

*End of Technical Design Specification v0.9 (2026-07-12: §4 as-built hardware
promoted from the KiCad PCB, §6 open items closed/narrowed; v0.8 FR-S40
calibration; v0.7 FR-S39 persistence + combined variant).*

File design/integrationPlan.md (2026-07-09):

# Phase-4 Integration Plan — Product Firmware

| Field | Value |
|---|---|
| Document | Phase-4 (integration) plan |
| Project | `windmeters-modbus-interface` firmware |
| Date | 2026-07-03 |
| Status | Ready to execute — phases 0–3 exited |
| Related docs | `design/TDS.md` v0.6 (the contract), `design/softwareArchitecture.md` (zero-ISR super-loop), `design/driverDevelopment.md` (driver results §3–§5), `software/hil/README.md` (harness + bench lessons) |

## 1. Purpose

Merge the three verified driver libraries into the single product firmware
(two builds), implement everything in TDS §3 that sits *between* the
drivers and the Modbus register map, and grow the HIL harness into the
NFR-TST01 acceptance/regression suite.

## 2. Inputs — what is already proven

| Component | Source | Verified |
|---|---|---|
| Pulse counting (`ws_*`) | `drivers/wind_speed/lib/ws` | 9/9 HIL: counts, rising-only, FR-S17 0.34%, FR-S27 saturation |
| ADC + angle (`wd_*`) | `drivers/wind_direction/lib/wd` | accuracy −3.8 LSB (divider), stability 0.6 LSB, end stops exact, FR-S38 float detect |
| Circular mean | `drivers/common/circmean` | exhaustive host tests + on-target self-test (FR-S14 exact) |
| Modbus RTU slave (`mb_*`) | `drivers/modbus_rtu/lib/mb` | 26/26 TDS §2 matrix + 40/40 endurance, 5.2 ms latency |
| Architecture | `softwareArchitecture.md` | zero-ISR super-loop (bench-forced; no concurrency surface) |
| Line discipline | remap switching, no HDSEL | bench-forced; PCB confirmed compatible (DE pull-down added) |

## 3. Project decisions

- **Location**: the existing `software/firmware/` scaffolding is adopted —
  its two-environment structure (`wind_speed` / `wind_direction` envs with
  `SENSOR_WIND_SPEED` / `SENSOR_WIND_DIRECTION` defines) stays, but its
  **framework migrates from `noneos-sdk` to `ch32v003fun`**: all drivers
  are built and verified on ch32v003fun; porting them would un-verify
  them. The stale HDSEL comment in its `main.c` header dies with the
  rewrite.
- **TDS editorial note**: FR-S01's criterion names the defines
  `SENSOR_WINDSPEED`/`SENSOR_WINDDIRECTION`; the scaffolding's
  `SENSOR_WIND_SPEED`/`SENSOR_WIND_DIRECTION` are kept — amend FR-S01's
  wording when the TDS is next touched.
- **Reuse in place, no copies**: `lib_extra_dirs` points at
  `../drivers/common`, `../drivers/wind_speed/lib`,
  `../drivers/wind_direction/lib`, `../drivers/modbus_rtu/lib` — a driver
  fix stays fixed in one place, and the driver test shells keep working.
- **`debug_uart` is excluded from release builds** (PD6 is the bus;
  FR-S19). Acceptance is black-box over Modbus — which is exactly what the
  register map's status/ID/diagnostic registers are for.
- **funconfig**: `FUNCONF_USE_DEBUGPRINTF 0`, `FUNCONF_SYSTICK_USE_HCLK 1`
  (both bench-mandated).
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

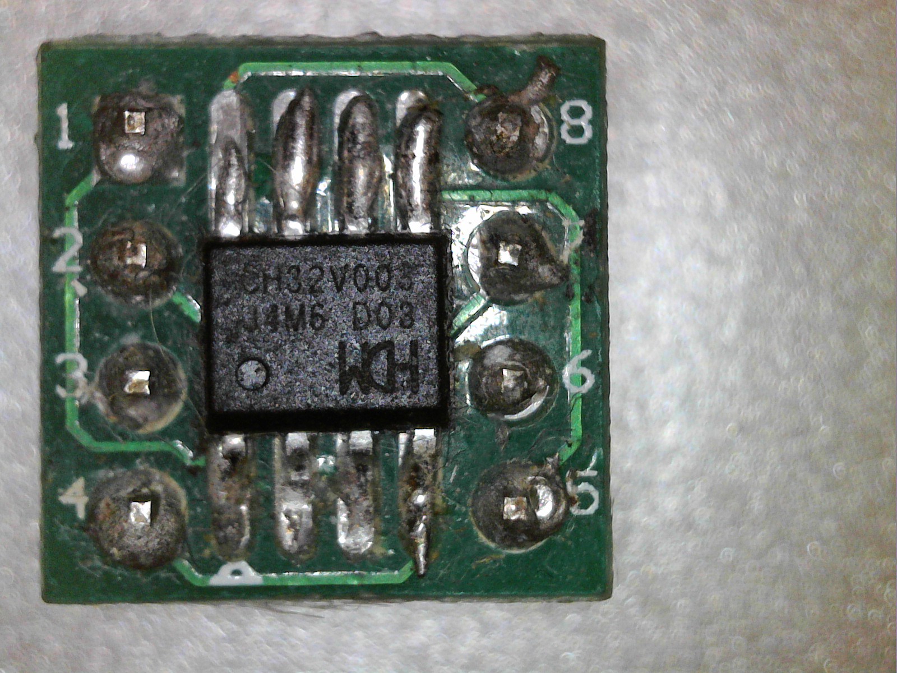
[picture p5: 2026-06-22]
documentation/WIN_20260622_09_02_07_Pro.jpg

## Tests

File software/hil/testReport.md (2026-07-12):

# HIL Test Report

Hardware-in-the-loop (HIL) testing on this project means the CH32V003 device-under-test (DUT) is exercised on a real bench: an **ADALM2000 (M2K)** generates stimulus (pulse trains, bursts, DC/ramp levels, a programmable supply, and byte-exact bit-banged Modbus/RS-485 frames), a **Saleae Logic16** captures the resulting digital signals through the Logic 2 application's built-in **MCP server**, the **WCH-LinkE** flashes and powers the DUT and serves as the UART monitor, and the sibling **`windmeters-modbus-interface-tester`** device acts as a well-formed Modbus master on the RS-485 bus. This report consolidates every HIL test executed to date — each with its setup, expected result, pass criteria, and pass/fail verdict grounded in the recorded numbers. The **authoritative requirement definitions (FR-Sxx, FR-MBxx, NFR-xx) live in `design/TDS.md`**; this document only cites them. The report is generated from the HIL check scripts under `software/hil/`, `design/driverDevelopment.md`, and `design/integrationPlan.md`, and **should be regenerated whenever those change**.

## Summary

| Area | Tests | Passing | Notable pending |
|---|---|---|---|
| Driver-phase HIL | 29 | 28 | P1-WS-BOUNCE (reed-relay bounce realism — needs a physical anemometer); FR-MB04/24/03 asserts within P3-MB-DEFERRED deferred to the MAX3485 rig / acceptance |
| Integration-stage HIL | 18 | 17 | INT-F-BUILD-02 (NFR-BLD01 reproducible-build hash compare, opt-in `-m reproducible`) |
| MAX3485-rig HIL (§9.1) | 20 | 20 | — (FR-S38 float-fault + recovery now validated) |
| Combined variant (`wind_combined`) | 4 | 4 | — |
| Persistence (FR-S39) | 3 | 3 | — |
| Live-sensor rig (2026-07-12) | 4 | 4 | FR-S11/S14 accuracy, VDD sweep, latency remain M2K-gated |
| **Totals** | **78** | **76** | **M2K-precision rows + opt-in (see Pending)** |

> Test counts include NOT-RUN/DEFERRED/PENDING rows so the matrix is honest; those rows are excluded from the "Passing" column. INT-F-BUILD-02 is present and available but is opt-in and was not part of the core stage-F green run, so it is counted as not-yet-passing here.

## Test setup

### Instruments

Three instruments make up the bench, plus the DUT and a companion master:

- **Saleae Logic16 (classic, digital-only variant) — Observer.** Captures digital signals, runs protocol analyzers, and exports CSV, driven via the Logic 2 application's built-in MCP server. It is the *classic* Logic16, digital-only: it **rejects `digitalThresholdVolts`** (its default range suits 3.3 V logic), and its **lead labels do NOT equal channel indices** (two 8-lead banks), so after any rewire signals must be located by an all-channel sweep.
- **ADALM2000 (M2K) — Stimulus generator.** Produces pulse trains, bursts, DC levels/ramps, and a programmable supply; its own scope also verifies analog. Driven via **libm2k 0.9.0**. **Firmware v0.33** is on the unit; **firmware ≥ 0.32 is MANDATORY** for libm2k 0.9.0 (the shipped fw v0.27 gave erratic AWG output and version errors). FW update method: copy `m2k.frm` onto the M2K mass-storage drive and eject — it self-flashes (~1 min, do not unplug).
- **WCH-LinkE — three jobs at once.** Flashes the DUT (`pio run -t upload`), supplies 3.3 V DUT power, and serves as the UART monitor RX. Invoked via PlatformIO's `pio.exe` at `%USERPROFILE%\.platformio\penv\Scripts\pio.exe`.
- **DUT:** a **CH32V003** (ch32v003fun toolchain).
- **Companion master:** the `windmeters-modbus-interface-tester` device also sits on the RS-485 bus as both a third bus node and a scriptable well-formed Modbus master (machine API documented in its `manual/api.md`).

### Environments

- **Saleae scripts** are stdlib-only — any Python ≥ 3.10 works (system Python 3.13 is fine).
- **libm2k** runs in a dedicated **Python 3.11 venv (`.venv-m2k`)** because libm2k wheels top out at cp311. The wheel alone is insufficient — it also needs the system-installed libm2k/libiio DLLs. One-time setup: (1) run `PlutoSDR-M2k-USB-Drivers.exe` as admin (IIO/RNDIS USB drivers); (2) run `libm2k-0.9.0-Windows-setup.exe` as admin (runtime DLLs); (3) `python3.11 -m venv .venv-m2k` then `.venv-m2k\Scripts\pip install libm2k-0.9.0-cp311-cp311-win_amd64.whl` (wheel from the libm2k GitHub release `python-wheels.zip`).
- **PlatformIO:** flashing/upload and UART monitoring go through `pio.exe` at `%USERPROFILE%\.platformio\penv\Scripts\pio.exe` (`pio run -t upload`).
- **Saleae MCP endpoint:** the Logic 2 built-in MCP server at `http://127.0.0.1:10530/mcp` (JSON-RPC over HTTP).

### Rigs

Three physical rigs are used, each reproducible from `software/hil/README.md`. All grounds (M2K, Saleae, WCH-LinkE, DUT — and both transceivers on the RS-485 rigs) are **common** throughout.

#### TTL rig (driver-development phases + integration stages 1–3)

- DUT is the CH32V003, powered at 3.3 V and flashed/monitored by the WCH-LinkE.
- The Saleae Logic16 observes DUT digital signals. Lead labels ≠ channel indices (two 8-lead banks) — after any rewire, run an all-channel sweep to locate signals. **DUT PD6 (debug UART / Modbus node) was on Saleae channel 8** during these phases.
- Driver-phase signal-verification sub-rig (`m2k_signal_check.py`): **M2K DIO0 → Saleae channel 15**; **M2K W1 → M2K scope 1+**; **M2K V+ → M2K scope 2+**.
- M2K AWG outputs are kept configured 0–3.3 V near the DUT (the hardware can swing ±5 V, beyond CH32V003 absolute maximums).
- Phase-3 / integration Modbus master: the **M2K acts as the shared-wire Modbus master in open-drain output mode** (`setOutputMode(DIO_OPENDRAIN)` + external pull-up), **permanently enabled** — the tristate direction-flip-per-transaction approach sprayed break glitches and phantom start bits and was rejected.

#### MAX3485 transceiver rig (2026-07-06 — `rs485_check.py` / `rs485_regs_check.py`)

- The DUT drives a MAX3485 transceiver. **DUT DI+RO (transceiver data-in / receiver-out node) → DUT PD6, observed on Saleae channel 8** on that node.
- **DUT DE+/R̄Ē (driver-enable / receiver-enable-bar, tied) → DUT PC2, observed on Saleae channel 15, with a 10 kΩ pull-down.**
- The **RS-485 bus A/B lines → M2K scope 1+ / 2+** for the analog wire view (optionally also Saleae ch0/ch1).
- The `windmeters-modbus-interface-tester` is the live well-formed master on the bus (driven through its HTTP machine API, `POST /api/v1/modbus`, which returns raw TX/RX frames for independent CRC verification); the DUT is the passive judge / responder.

#### Second-MAX3485 M2K-driven raw master (`rs485_raw_check.py`)

- A **second MAX3485** transceiver, driven directly by the M2K, injects byte-exact / malformed frames as a raw master, sharing the same RS-485 bus as the DUT and the tester (**three nodes total**).
- Wiring: **M2K DIO0 → DI** (data in); **M2K DIO1 → DE+/R̄Ē** (driver-enable, tied); **M2K V+ → VCC (3.3 V)** of that second MAX3485.
- Every raw-master script MUST enable V+ itself (`ps.enableChannel(0, True)` + `pushChannel(0, 3.3)`) — an unpowered MAX3485 sits inert. The static DE/DI test (drive space, drive mark, release) is the 10-second wiring proof.

### Bench quirks that change how results must be read

- **Analyzer unreliable at 9600 baud.** The Logic 2 Async Serial analyzer scrambles byte values at 9600 baud on this setup while the raw edges are perfect. Binary/Modbus captures are therefore decoded with `saleae_serial.uart_decode()` over the raw-edge export, using `decode_events(..., sync_to_newline=False)` for binary (the text first-LF rule would silently discard LF-free captures). Accuracy-of-record for `wd_check.py` uses a **resistor divider**, not the analyzer/AWG.
- **M2K analog-out session state is fragile.** Within one context, repeated output reconfiguration misbehaves (`stop()` wedges the DAC until `reset()`; a second cyclic `push()` at the same rate is silently ignored; stale state leaks). The reliable pattern is a **fresh `m2kOpen()` + calibrate per analog stimulus configuration** (~1.5 s each; digital out is unaffected). The libm2k context MUST stay OPEN while the DUT-side capture runs — `contextClose()` idles the AWG. Rapid close/reopen can transiently fail ("Cannot set the number of kernel buffers") — retry with ~1 s backoff. First pattern-generator period after `push()` is anomalous (judge steady state); large cyclic digital buffers get truncated (scale to ~10k samples/period); AWG sample rates snap to a 75 MS/s/10ⁿ ladder and DC droops between wraps (generate DC at 750 kS/s or via `setVoltage()`). A "disabled" AWG channel is NOT high-impedance (~50 Ω to idle) so it cannot emulate a disconnected sensor — physically lift the wire.
- **M2K absolute-voltage accuracy is not trustworthy.** DMM-anchored, the AWG outputs setpoint +25 mV (constant offset) and the scope reads ~1 %/−30 mV low (affine, drifts ~10 mV between sessions). **Never assert DUT accuracy against M2K absolute voltages** — use a resistor divider from DUT VDD (ratiometric, DMM-measured ratio) as the method of record. The M2K stays fine for dynamics, end stops, and anything ratio-cancelled.
- **Tester buffers overheard bus traffic.** The tester never stops listening; its Modbus master only drains its UART RX during its own transactions, so it buffers every byte the raw master puts on the shared bus, then parses the stale backlog on its next transaction and reports CRC_ERR (a log showed ~30 overheard frames ahead of the true response). **One throwaway read IS the flush** — retry once on `crc_error` before trusting a tester-API read after raw-master traffic (`rs485_raw_check.dut_diag`).
- **Noise floods take the silent-discard path.** Random-byte floods do NOT move the DUT's CRC counter (register 30009) — those bytes arrive framing-poisoned (FE/overflow) and are silently discarded; only cleanly-framed-wrong-CRC frames (e.g. split halves) increment the counter. **Assert flood recovery by behavior, not by that counter.** Inter-frame marks in composed patterns must exceed **t3.5 (4.01 ms)** or the DUT correctly coalesces frames into one discard — the house gap is 48 bit times of mark (5 ms); a 2.5 ms gap between a garbage tail and a recovery request merged them.
- **Saleae MCP / capture quirks.** `add_analyzer` settings need tagged values (`{"Input Channel": {"numberValue": 8}}`); `export_raw_data_csv` requires `analogDownsampleRatio` even for digital-only; the Async Serial data-table CSV holds the literal character per byte (CR/LF arrive as embedded newlines inside quoted fields — don't strip); a capture starting mid-byte yields garbage + one framing error before the first line boundary (judge from the first clean newline onward); the classic Logic16 rejects `digitalThresholdVolts` (omit it).
- **Baud tolerance.** The DUT answers master baud offsets to ±3 % both directions (measured against the ladder read-back rate); its own HSI adds ~+0.3 %.
- **DUT-side UART / timing gotchas.** HDSEL half-duplex idles the line floating (framing errors on bursty output) so `common/debug_uart` runs plain TX with idle mark driven; HDSEL also intermittently swallows the first RX byte after idle (~35 %, no error flags), so the Modbus driver abandoned HDSEL for a **RX-on-PD6-default-map / TX-remapped-in-for-response** discipline. Interrupts are suspect on this toolchain path (an RXNE ISR corrupted ~1/3 of frames with no USART error flags; **polled RX** fixed it — the architecture is now zero-ISR). A master must release the wire immediately after its last stop bit (the DUT replies ~5 ms later; holding the line collides).
- **Timing-scale gotcha.** ch32v003fun SysTick defaults to HCLK/8 — define **`FUNCONF_SYSTICK_USE_HCLK 1`** for raw `SysTick->CNT` pacing or everything runs 8× slow. Count-vs-frequency asserts must scale to the **MEASURED window duration** (report-line timestamp deltas), because the DUT window is HSI-paced (±1 %) — a nominal-window compare at 1 kHz is off by several counts while the DUT behaves exactly per FR-S06.

## Driver-phase HIL tests

Common rig (`driverDevelopment.md` §2.3–2.5): DUT is a **CH32V003J4M6 (SOP-8)** on a breadboard, powered at 3.3 V from a WCH-LinkE that also flashes it via SDI on PD1 (`pio run -t upload`). Observation is the classic Saleae Logic16 (digital-only) via the Logic 2 MCP server; DUT PD6 debug UART lands on **Saleae channel 8**. Stimulus is the ADALM2000 via libm2k in the Python 3.11 venv (`software/hil/.venv-m2k`): 16 DIO @ 3.3 V pattern generator/AWG for pulses, 2 AWG channels for DC/ramp, programmable supply for the VDD sweep — the M2K crystal timebase is independent of the DUT HSI, and its scope channels observe analog that the Logic16 cannot. Common ground is mandatory. Firmware built with `FUNCONF_USE_DEBUGPRINTF 0` and `FUNCONF_SYSTICK_USE_HCLK 1`; all tracing is short ASCII over PD6 (or the bus itself for Modbus). M2K firmware v0.33 (libm2k 0.9.0 requires ≥ 0.32).
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

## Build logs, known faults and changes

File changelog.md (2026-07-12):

# Changelog

All notable changes to the Windmeters Modbus Interface are documented in
this file.

The format is based on [Keep a Changelog](https://keepachangelog.com/), and
this project adheres to [Semantic Versioning](https://semver.org/). No
firmware release has been tagged yet — the version-byte registry lives in
[`software/firmware/RELEASES.md`](software/firmware/RELEASES.md); firmware
version 1 will be tagged `fw-v1` at the first release.

---

## [Unreleased]

### Added — design & requirements

- Design document chain: `scratchBook.md` (brainstorm: sensors, power
  chain, ADC strategy, Modbus conventions, anemometer calibration
  C = 2πr/η) → **`TDS.md` v0.6** — 67 active requirements with measurable
  pass/fail criteria, matured through a 38-finding multi-agent gap audit,
  a 30-issue verification pass, and a fresh-eyes re-check. Key decisions:
  persisted holding registers (FR-S39), hardware-only device addressing
  (solder jumper + build variant), exception 04 never emitted, standard
  exception codes only, atomic FC16, no-clamp range rejection.
- `softwareArchitecture.md`: cooperative super-loop, later amended to
  **zero-interrupt** after bench findings (see firmware below).
- `driverDevelopment.md`: three-driver plan with HIL matrices per phase;
  `integrationPlan.md`: six-stage product-firmware plan with per-stage
  results and the hardware-gated test set (MAX3485 rig + real PCB).
- Two decisions were documented as deferred, then both subsequently taken
  and implemented (see firmware): holding-register persistence (the
  volatile-register coherence review → FR-S39) and the combined-sensor
  firmware variant (→ `wind_combined`).
- **`TDS.md` v0.9 (2026-07-12)** — promoted the as-built hardware design from
  the KiCad PCB into a new **§4 Hardware** (MCU pin/net map, RS-485 front-end,
  24 V PoE power chain, sensor front-ends, connectors, anemometer-calibration
  derivation), reconciled the stale FR-MB23 HDSEL note with the shipped
  remap-switching discipline, updated the pulses-per-rotation note for FR-S40,
  and closed/narrowed the §6 open items (response latency measured 4–5 ms;
  volatile-register and combined-variant decisions recorded; temperature range
  bounded by the as-built parts). Flagged as-built deltas vs the old
  `scratchBook.md` notes (fail-safe R2/R3 designators, power caps 100 µF/4.7 µF,
  two RJ14 jacks, no ADC RC filter, unspecified zener).

### Added — hardware (KiCad)

- Schematic and PCB: CH32V003J4M6 (SOP-8), MAX3485 (DI+RO on PD6,
  DE+R̄Ē on PC2), 24 V passive PoE → DB207 bridge (polarity protection) →
  HLK-K7803 3.3 V buck, dual RJ45 daisy-chain, RJ14 sensor connector,
  120 Ω terminator behind a solder jumper, PC4 address solder jumper,
  SM712 TVS + A/B fail-safe bias, anemometer input RC debounce + zener.
- **10 k pull-down on DE/R̄Ē** — holds the transceiver in receive mode
  while the MCU is in reset or being flashed (a floating DE could jam the
  shared bus).

### Added — drivers (all HIL-verified on silicon)

- `debug_uart` (PD6 TX tracer): 13 879 clean lines, zero errors.
- `wind_speed` (`ws`): TIM2 ETR pulse counting on PC1 — remap confirmed on
  silicon; 9/9 matrix (counts, rising-edges-only, window ±0.34% vs FR-S17's
  ±2%, saturation 65535-never-wrapped).
- `wind_direction` (`wd`) + `circmean` (Q15 sine table + integer CORDIC):
  accuracy −3.8 LSB against a DMM-measured divider (±10 budget), stability
  0.6 LSB, end stops exact, float detection proven; circular mean host-
  tested exhaustively (identity error 0 LSB over all 3600 angles) plus an
  on-target boot self-test.
- `modbus_rtu` (`mb`): 26/26 TDS §2 matrix + 40/40 endurance on a TTL rig,
  response latency 5.2 ms (budget 15/100 ms). Three bench-forced design
  changes: **HDSEL abandoned** (intermittently swallows the first byte
  after bus idle — replaced by a remap-switching line discipline: RX
  natively on PD6, TX remapped in only for the response; self-echo
  eliminated), **interrupts abandoned** (an RXNE ISR corrupted ~1/3 of
  frames with no error flags; polled RX is provably lossless at 9600 baud
  — the architecture is now zero-ISR with no concurrency surface), and
  **TX made push-pull** (first MAX3485 rig session: the open-drain TX
  inherited from the shared TTL wire has no pull-up behind the
  transceiver and transmitted a solid break — the TTL rig's pull-up had
  masked a ship-blocking defect; RO is tri-stated during DE, so push-pull
  is contention-free).

### Added — product firmware (`software/firmware/`, stages A–F)

- ch32v003fun project referencing the verified driver libraries in place;
  two build variants + `_test` envs (bench-only watchdog hang hook);
  NFR-RES01 ceilings enforced as hard build gates.
- `board.c`: FR-S18 init order, jumper address (all four addresses
  verified on the real jumper, including latch-until-reset semantics),
  IWDG ~1 s with PVD-gated feeding — watchdog hang→recovery < 2.5 s with
  all defaults restored. Silicon findings: LSI must be started before
  IWDG configuration; the SPL DBGMCU address faults this core (no debug
  freeze — flashing under a live watchdog bench-verified OK).
- `regs.c`: the complete TDS §2.7/§2.8 register image — per-build zeros,
  identification (build byte + version byte from `version.h`), status
  bits, uptime, CRC/served counters, pulse-age, gust.
- `meas_speed.c`/`meas_dir.c`: 40002-driven measurement windows with
  abort-on-write, ms-domain speed scaling (compile-time calibration
  factor with static-assert bounds), low-speed cut-off, saturation;
  10 Hz direction updates with offset/wrap and sticky float fault.
- `avg.c`: boxcar/two-stage averaging engine (proven live at N = 6000),
  gust tracking with correct decay, warm-up partial means (the
  zero-padding trap defeated: partial mean reads true value, not diluted).
- FR-S32 version chain: `version.h` single source + `RELEASES.md`
  registry + on-DUT verification.
- **`wind_combined` variant (build 0x03, address 32/37)** — one Modbus
  slave serving both sensors (integrationPlan §10). Capability-macro
  refactor (`sensors.h` maps the three `SENSOR_WIND_*` selectors to
  `HAVE_WIND_SPEED`/`HAVE_WIND_DIRECTION`), per-sensor measurement services,
  per-sensor averaging cursors (the two rings advance independently), speed
  pulse count at 30005 and direction raw ADC at the new 30013 (map edge
  extends 0x000C → 0x000D on this build). 6812 B flash / 1192 B RAM; the
  single-sensor builds are unchanged. **Validated over RS-485 at address 32,
  77/77** (`rs485_regs_check.py --build combined --speed-live`) with both
  sensors live simultaneously — divider on PA2 + a 30 Hz M2K W2 → PC1 pulse
  train (`m2k_pulse.py`): one FC04 image carries dir 182.8° + speed 29.4 m/s
  (count 30, gust 29.4, dir-raw at 30013), the per-cursor averaging verified
  live via the FR-S30 dance (both first windows + both cursors filled), full
  protocol/atomicity/FR-S31, served delta exact. The byte-exact raw suite
  (split 10/10, floods 3/3 incl. 60 s soak, baud ±3%, latency 1000/1000) is
  also green on combined — the full §9.1 treatment, matching the single
  builds. An adversarial multi-agent review of the diff found no confirmed
  defects.
- **Persistent holding registers (FR-S39).** The four holding registers
  (40001–40004) now survive reset/power-loss — the CH32V003 has no EEPROM,
  so `persist.c` flash-emulates it: two 64-byte pages at the top of flash
  (above the NFR-RES01 code gate) as a ping-pong log, one 16-byte CRC'd
  record per page, newest-sequence-wins, power-loss atomic, save-on-change.
  `regs_init` seeds the holdings from flash (blank/corrupt → §2.8 defaults,
  so FR-S21's defined state still holds); a changed set is committed from
  the main loop *after* the Modbus response (the ~6 ms flash op stays out
  of the FR-MB20/21 latency path). ~560 B flash / 8 B RAM. This takes the
  long-deferred TDS §5 persistence decision (resolution (c), all four
  registers). Bench-verified 7/7 (`rs485_persist_check.py`): non-default
  settings survive a watchdog reset, an erased store falls back to
  defaults, and the ping-pong handles successive saves. Requirements
  updated: new FR-S39, FR-S21 carve-out, holding-map + interface-assumption
  notes.
- **Runtime + persistent anemometer calibration (FR-S40, TDS v0.8).** The
  anemometer calibration moved from a compile-time-only `WS_C_SCALED` to two
  persistent holding registers — **40005** (calibration factor C, 0.001
  m/rotation) and **40006** (pulses per rotation) — with the compile-time
  values as factory defaults. FR-S06 speed is now
  `count × C × 10 / (window_ms × pulses_per_rotation)`, so one firmware image
  serves any anemometer with no rebuild: a field installer sets the two
  registers over Modbus and they persist. A change clears the averaging
  accumulator (like FR-S30). The persistence record grew 16 → 20 B with a
  bumped magic, so a pre-existing store cleanly re-defaults. Verified on the
  deployed combined unit: defaults [980, 1], writes + range-reject (exc 03),
  the four-pulse case set live to 40006 = 4. FR-S25/FR-S06 reworked, FR-S39
  now covers six registers, §2.8 map extended.

### Added — HIL harness (`software/hil/`)

- Scripted bench: Saleae Logic 2 via its built-in MCP server + ADALM2000
  via libm2k (Python 3.11 venv), WCH-LinkE flashing — stimulus, capture,
  and assertion fully automated; M2K firmware updated 0.27 → 0.33.
- Check scripts (each standalone): `smoke_test`, `blinky_check`,
  `uart_check`, `m2k_smoke`, `m2k_signal_check` (15/15 signal
  verification), `ws_check`, `wd_check`, `mb_check`, `regs_check`,
  `meas_check`, `avg_check`, `version_check`, `rs485_check` (MAX3485
  rig: passive judge of live master traffic — DE timing, storm,
  idle-bias, latency), `rs485_regs_check` (full register read/write
  matrix over RS-485, driven through the tester's machine API —
  build-aware: **speed 62/62, direction 72/72**, the latter adding the
  north-offset→angle wraparound check, exact to 0 LSB), `rs485_raw_check`
  (second-MAX3485 raw master on M2K DIO0/DIO1: split frames, garbage
  floods incl. 60 s soak, baud margin to ±3%, 1000-request latency
  histogram ~4.1 ms — §9.1 byte-exact set green on both builds).
- **§9.1 (MAX3485 rig) complete on all three variants** over real RS-485
  (speed 30, direction 31, combined 32). Enabled by a second MAX3485 as an
  M2K-driven raw master (byte-exact malformed vectors) and the tester's
  machine API as a well-formed scripted master returning raw wire frames.
  The last row, **FR-S38 wind-direction float-fault + recovery, was
  validated over the transceiver** (`rs485_float_check.py`): PA2 wiper
  lifted → DIR_FAULT + 65535 sentinels (fault 4/4); re-driven → sticky
  fault clears, real angle returns (recovery 4/4).
- `acceptance/`: pytest suite (NFR-TST01 core) — one command per flashed
  variant; **green on both builds** (speed 6/6, direction 6/6), including
  build-gate checks and an opt-in reproducible-build comparison.
- A bench-quirk catalogue in `software/hil/README.md` (Saleae analyzer
  limits, M2K session-state behavior, AWG/scope accuracy, DUT UART
  gotchas) — hard-won knowledge that keeps future debugging short.

### Added — documentation & tooling

- **Comprehensive Doxygen** on every project header (file blocks with FR-ID
  rationale and `@ref` cross-links; `@param`/`@return`/`@note` on all public
  functions, macros, structs and members) — comment-only, all variants build
  to identical sizes.
- **`Doxyfile`** builds a single browsable site with the project README as
  the landing page, folding the design docs (TDS, integration plan,
  architecture, driver development, scratchbook) + HIL report in as pages
  alongside the API reference; generates with zero warnings.
- **UML diagrams** (`design/diagrams/`, PlantUML sources + rendered PNGs):
  a component diagram, a zero-ISR super-loop sequence diagram, and the
  Modbus RTU line-discipline state machine — embedded in
  `softwareArchitecture.md` §7.
- **`design/README.md`** indexes the design-document chain and variants;
  root docs (README, contributing) updated for the three variants,
  persistence, and the documentation site.
- **`softwareArchitecture.md` updated for the combined variant
  (2026-07-12)** — three-build scope with the `sensors.h` capability-macro
  gating, a "combined build: both sensors, one loop, zero new mechanism"
  design decision (per-sensor `avg.c` cursors, 30005/30013 split, unchanged
  latency), the stale HDSEL/RX-ISR §3 wording reconciled with the shipped
  remap-switching discipline, the module split extended (`sensors.h`,
  `avg.c`, `persist.c`, `mb.c` referenced in place), and as-built sizes for
  all three variants (speed 4408 B / 908 B, direction 6824 B / 916 B,
  combined 7604 B / 1216 B against the NFR-RES01 ceilings).

---

*Older working history predating this changelog lives in the git log
(initial scaffolding, first KiCad PCB and power-circuit commits).*

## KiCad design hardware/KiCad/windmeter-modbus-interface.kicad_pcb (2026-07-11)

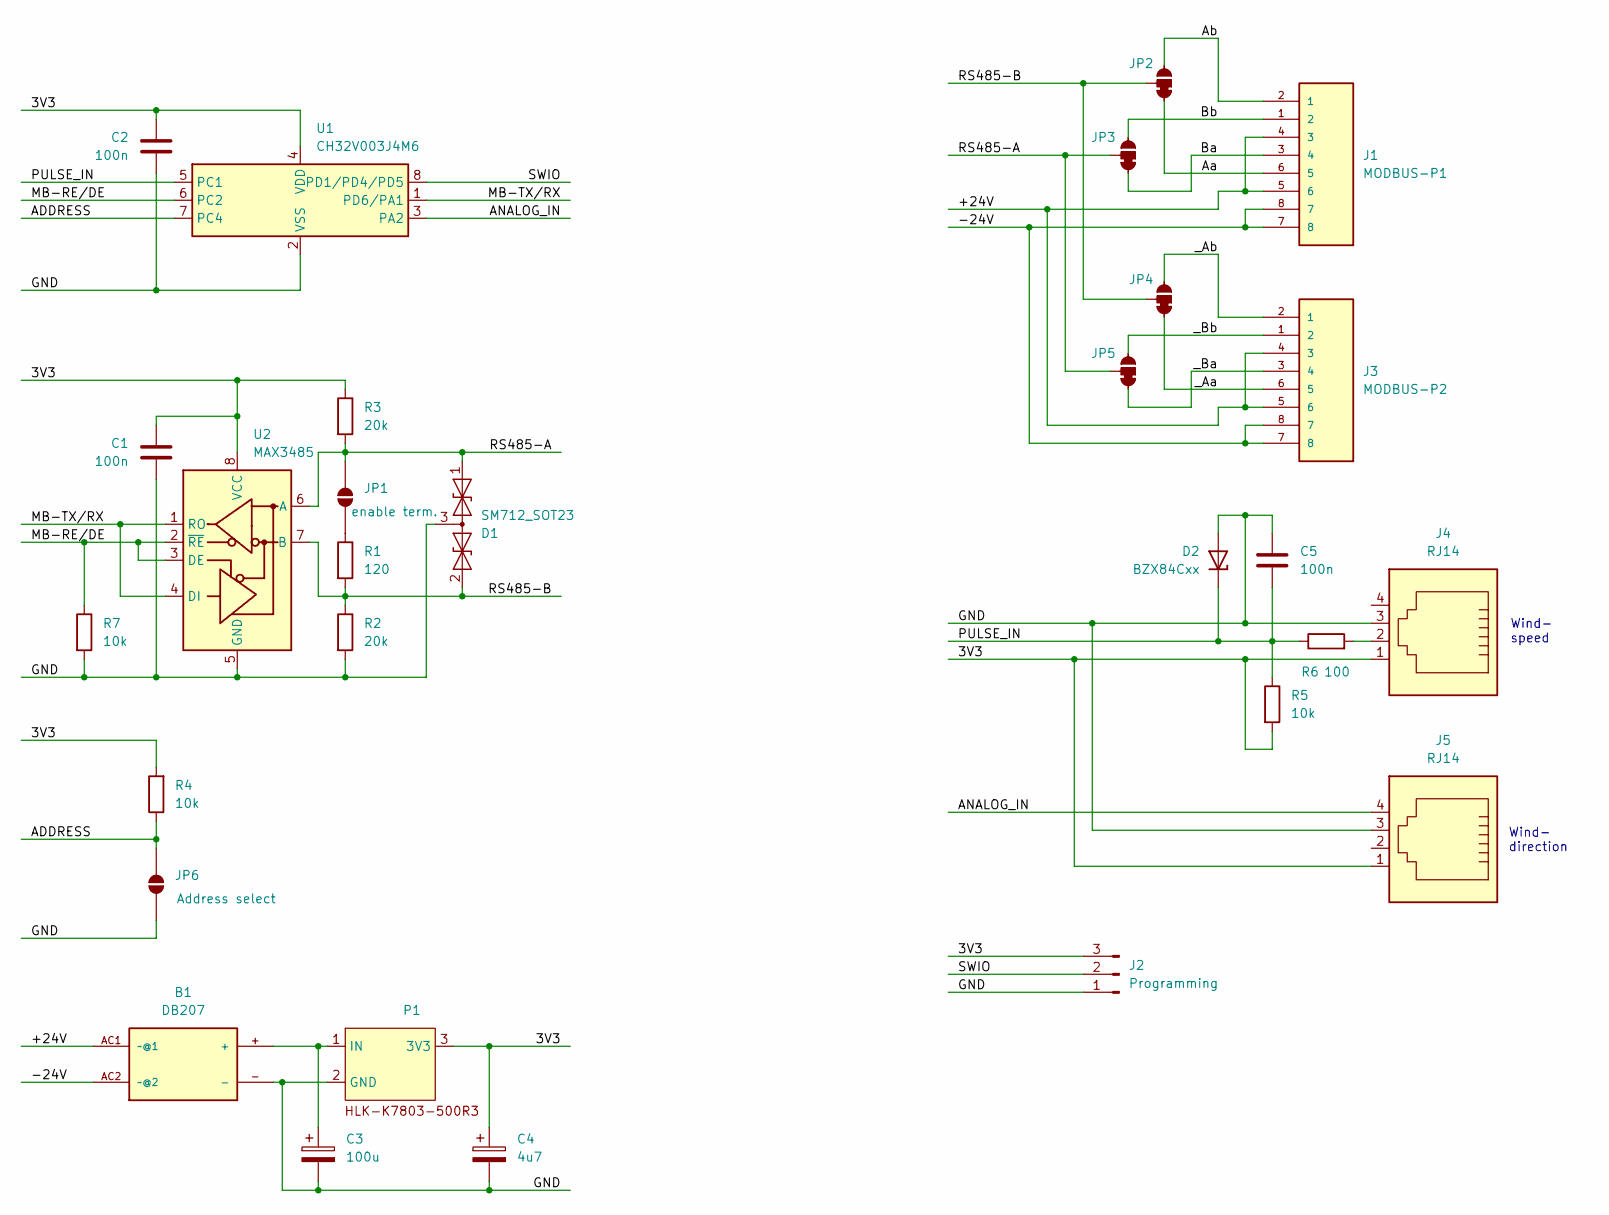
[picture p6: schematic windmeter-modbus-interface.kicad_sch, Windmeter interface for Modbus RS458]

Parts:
B1: DB207; DB207-DIP-4
C1, C2, C5: 100n; C_1206_3216Metric_Pad1.33x1.80mm_HandSolder
C3: 100u; CP_Radial_D8.0mm_P5.00mm
C4: 4u7; CP_Radial_D5.0mm_P2.50mm
D1: SM712_SOT23; SOT-23
D2: BZX84Cxx; SOT-23
J1: MODBUS-P1; CONN_215877-1; PARTREV AF1
J2: Programming; PinHeader_1x03_P2.54mm_Vertical
J3: MODBUS-P2; CONN_215877-1; PARTREV AF1
J4, J5: RJ14; RJ14_Connfly_DS1133-S4_Horizontal
JP1: enable term.; SolderJumper-2_P1.3mm_Open_Pad1.0x1.5mm
JP2, JP3, JP4, JP5: SolderJumper-3_P1.3mm_Bridged12_Pad1.0x1.5mm_NumberLabels
JP6: Address select; SolderJumper-2_P1.3mm_Open_Pad1.0x1.5mm
P1: HLK-K7803-500R3
R1: 120; R_1206_3216Metric_Pad1.30x1.75mm_HandSolder
R2, R3: 20k; R_1206_3216Metric_Pad1.30x1.75mm_HandSolder
R4, R5, R7: 10k; R_1206_3216Metric_Pad1.30x1.75mm_HandSolder
R6: 100; R_1206_3216Metric_Pad1.30x1.75mm_HandSolder
U1: CH32V003J4M6; JEITA_SOIC-8_3.9x4.9mm_P1.27mm
U2: MAX3485; SOIC-8_3.9x4.9mm_P1.27mm

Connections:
/3V3: C1.1, C2.1, C4.1, J2.3, J4.1, J5.1, P1.3 (3V3), R3.1, R4.2, R5.2, U1.4 (VDD), U2.8 (VCC)
/+24V: B1.AC1 (~@1), J1.4 (3), J1.5 (6), J3.4 (3), J3.5 (6)
/-24V: B1.AC2 (~@2), J1.7 (8), J1.8 (7), J3.7 (8), J3.8 (7)
/ADDRESS: JP6.2 (B), R4.1, U1.7 (PC4)
/ANALOG_IN: J5.4, U1.3 (PA2)
/Aa: J1.6 (5), JP2.1 (A)
/Ab: J1.2 (1), JP2.3 (C)
/Ba: J1.3 (4), JP3.1 (A)
/Bb: J1.1 (2), JP3.3 (C)
/GND: B1.-, C1.2, C2.2, C3.2, C4.2, C5.1, D1.3 (common), D2.1 (A), J2.1, J4.3, J5.3, JP6.1 (A), P1.2 (GND), R2.2, R7.2, U1.2 (VSS), U2.5 (GND)
/MB-RE/DE: R7.1, U1.6 (PC2), U2.2 (~RE), U2.3 (DE)
/MB-TX/RX: U1.1 (PD6/PA1), U2.1 (RO), U2.4 (DI)
/PULSE_IN: C5.2, D2.3 (K), R5.1, R6.1, U1.5 (PC1)
/RS485-A: D1.1 (A1), JP1.2 (B), JP3.2 (B), JP5.2 (B), R3.2, U2.6 (A)
/RS485-B: D1.2 (A2), JP2.2 (B), JP4.2 (B), R1.2, R2.1, U2.7 (B)
/SWIO: J2.2, U1.8 (PD1/PD4/PD5)
/_Aa: J3.6 (5), JP4.1 (A)
/_Ab: J3.2 (1), JP4.3 (C)
/_Ba: J3.3 (4), JP5.1 (A)
/_Bb: J3.1 (2), JP5.3 (C)
unnamed: J4.2, R6.2
unnamed: JP1.1 (A), R1.1
unnamed: B1.+, C3.1, P1.1 (IN)

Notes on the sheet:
Wind- speed
Wind- direction

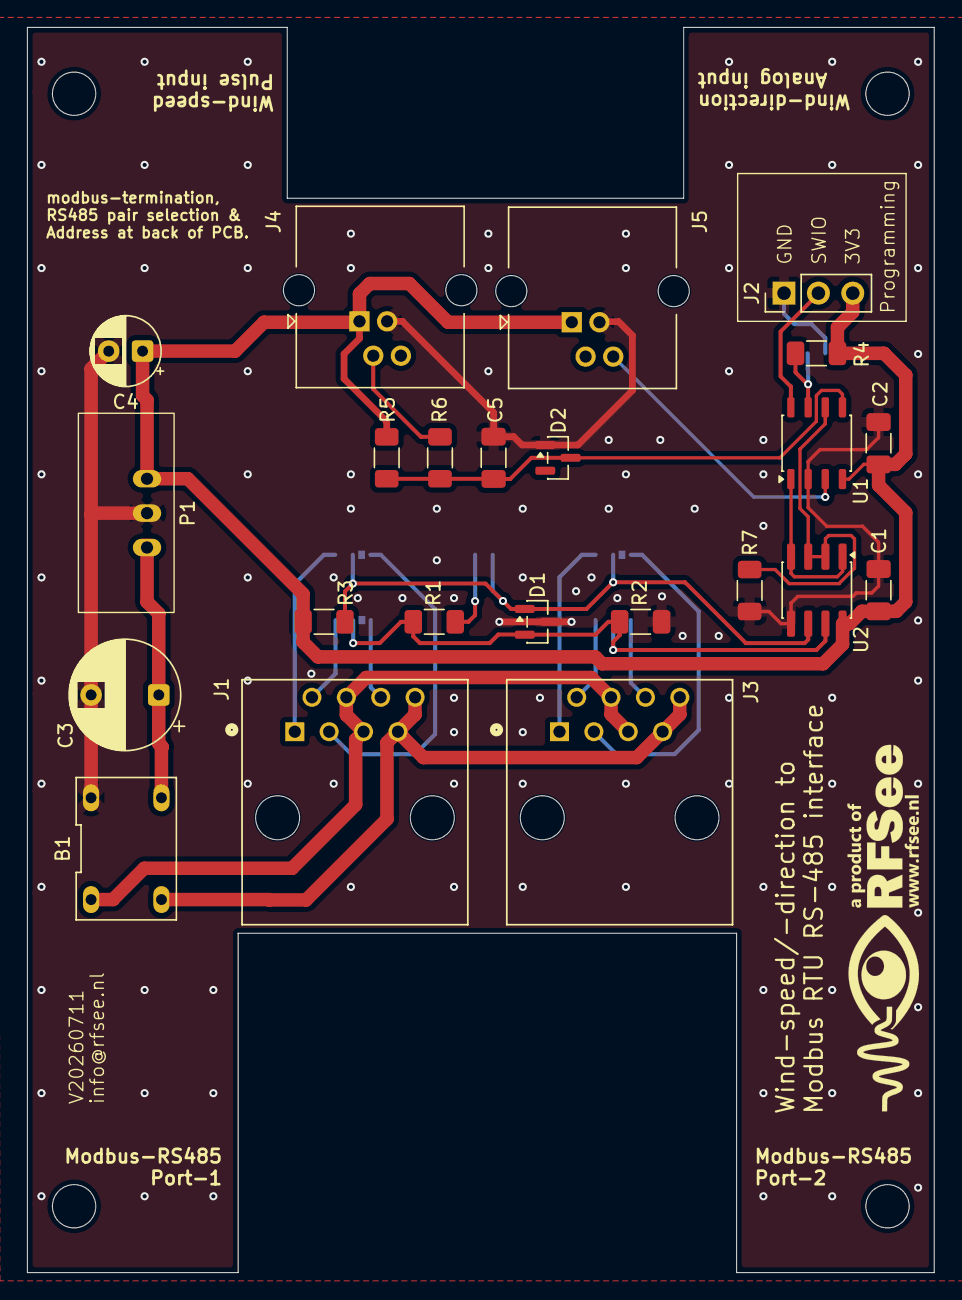
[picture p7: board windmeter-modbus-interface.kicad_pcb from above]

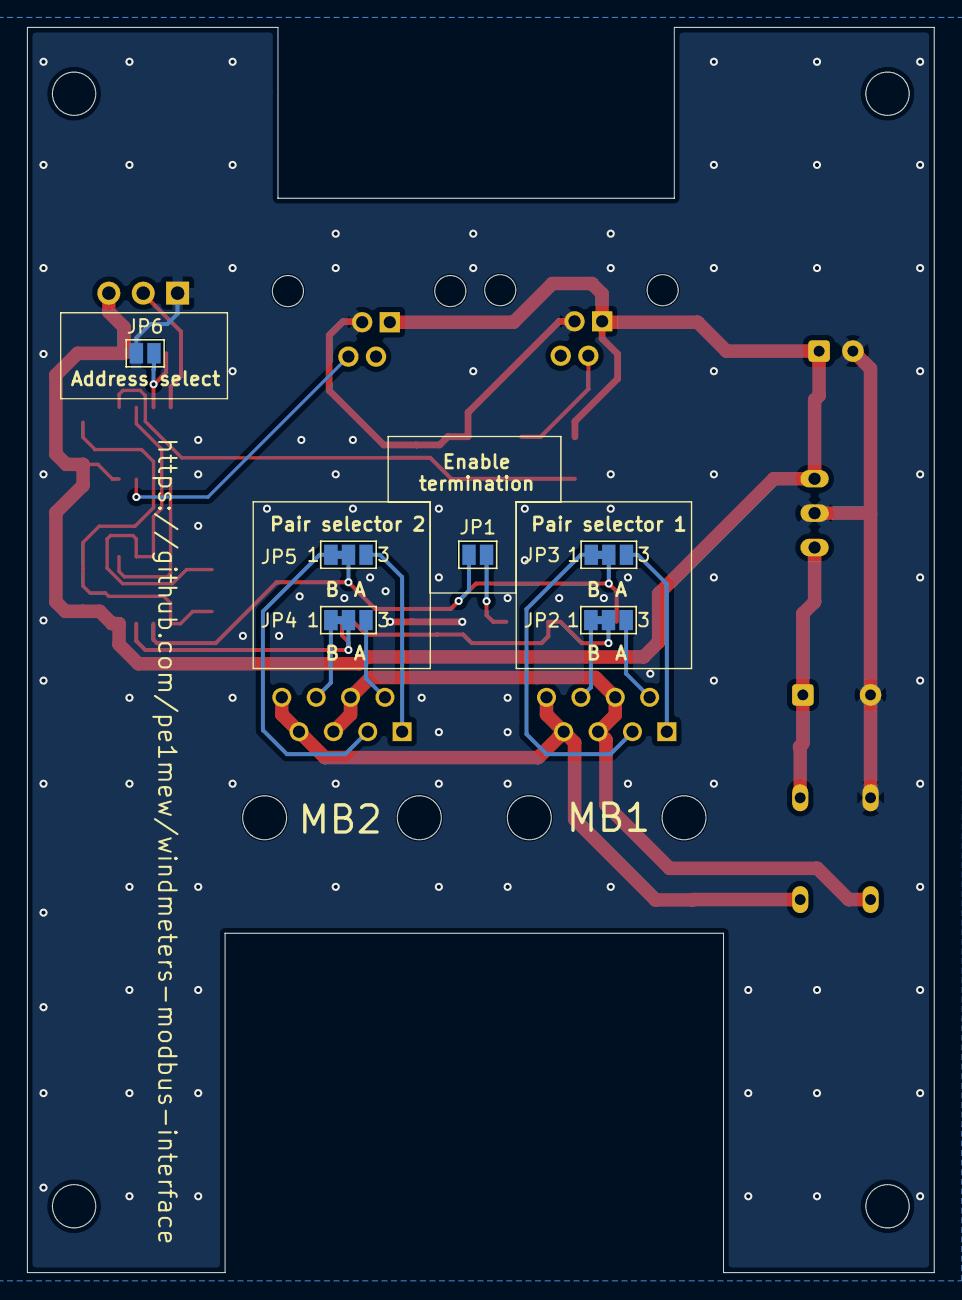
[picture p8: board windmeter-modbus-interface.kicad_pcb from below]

Board: 2 copper layers, 67.0 x 92.0 mm, 29 parts (6 on the bottom side), 23 nets.

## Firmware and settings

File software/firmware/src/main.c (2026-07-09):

/*
 * Windmeter Modbus interface — product firmware (CH32V003J4M6, SOIC-8)
 *
 * Zero-ISR cooperative super-loop (design/softwareArchitecture.md).
 * Stage D state (design/integrationPlan.md): full register image (regs.c)
 * + real measurement services (meas_speed.c / meas_dir.c). The averaging
 * engine (30003/30004/30012 + warm-up semantics) is stage E.
 *
 * Pin assignment: design/scratchBook.md — PD6 Modbus line (remap-switching
 * discipline, no HDSEL), PC2 DE/R̄Ē, PA2 wind-direction ADC, PC1 anemometer
 * pulses, PC4 address jumper, PD1 SWIO.
 */

#include "sensors.h" /* variant selection -> HAVE_WIND_SPEED/DIRECTION */
#include "board.h"
#include "ch32fun.h"
#include "mb.h"
#include "meas.h"
#include "regs.h"

#ifdef HAVE_WIND_SPEED
#include "ws.h"
#endif
#ifdef HAVE_WIND_DIRECTION
#include "wd.h"
#endif

int main(void)
{
	SystemInit();
	funGpioInitAll();

	/* FR-S18 init order:
	 * (1) PC2/DE low first + (2) PC4 address latch + IWDG + PVD ... */
	board_init_early();
	/* (3) sensor front-end(s) ready — a combined build inits both. */
#ifdef HAVE_WIND_SPEED
	ws_init();
#endif
#ifdef HAVE_WIND_DIRECTION
	wd_init(); /* includes ADC self-calibration */
#endif
	/* regs_init loads the persisted holdings (FR-S39) BEFORE the
	 * measurement services latch the window, so the first window already
	 * uses the stored duration — no spurious first-window abort at boot. */
	regs_init(board_mb_address());
#ifdef HAVE_WIND_SPEED
	meas_speed_init();
#endif
#ifdef HAVE_WIND_DIRECTION
	meas_dir_init();
#endif
	/* (4) USART receiver enabled last. */
	mb_init(regs_cfg());

	const uint32_t second_ticks = FUNCONF_SYSTEM_CORE_CLOCK;
	uint32_t t_second = SysTick->CNT;

	while (1)
	{
		mb_poll();
		regs_service(); /* FR-S30: 40002/40003 change -> accumulator clear */
		regs_persist_service(); /* FR-S39: save changed settings to flash
		                         * (after mb_poll sent any response) */
#ifdef HAVE_WIND_SPEED
		meas_speed_service();
#endif
#ifdef HAVE_WIND_DIRECTION
		meas_dir_service();
#endif

		if ((uint32_t)(SysTick->CNT - t_second) >= second_ticks)
		{
			t_second += second_ticks;
			regs_second_tick();
		}

#ifdef TEST_HOOKS
		if (regs_test_hang_requested())
			for (;;)
				; /* FR-S20 test: stop servicing AND feeding — dog bites */
#endif
		/* FR-S20: refresh only here, at the end of a full loop pass, and
		 * only while the rail is healthy (FR-S22). */
		if (board_power_ok())
			board_iwdg_feed();
	}
}

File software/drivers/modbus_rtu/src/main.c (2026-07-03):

#include "ch32fun.h"
#include "mb.h"

// Modbus RTU driver HIL test shell — TTL-level rig (no MAX3485 yet).
//
// NO debug UART here: PD6 IS the bus (FR-S19 — never transmit except in
// response to a valid addressed request). Observability = the bus itself,
// decoded on the Saleae; DE on PC2 is observable on a second channel.
//
// Slave address 30 (wind-speed build value, FR-S03; PC4 jumper handling
// arrives at integration). Holding registers mirror TDS §2.8 exactly;
// input registers serve known patterns for read/byte-order tests plus
// live uptime and the driver's own diagnostic counters.

static uint16_t h_offset = 0;    // 40001: 0..3599, default 0
static uint16_t h_window = 1000; // 40002: 100..60000, default 1000
static uint16_t h_avg = 10;      // 40003: 1..600, default 10 (FR-S31)
static uint16_t h_cutoff = 4;    // 40004: 0..50, default 4

static const mb_holding_t holdings[] = {
	{0x0000, 0, 3599, &h_offset},
	{0x0001, 100, 60000, &h_window},
	{0x0002, 1, 600, &h_avg},
	{0x0003, 0, 50, &h_cutoff},
};

static volatile uint32_t uptime_s;

// FR-S31: (averaging window x 1000) >= measurement window, evaluated
// against the staged pair (falls back to current values if not staged).
static bool cross_validate(const uint16_t *addrs, const uint16_t *vals,
                           uint8_t n)
{
	uint16_t window = h_window;
	uint16_t avg = h_avg;
	for (uint8_t i = 0; i < n; i++) {
		if (addrs[i] == 0x0001)
			window = vals[i];
		if (addrs[i] == 0x0002)
			avg = vals[i];
	}
	return (uint32_t)avg * 1000u >= window;
}

static uint16_t input_read(uint16_t addr, bool *ok)
{
	switch (addr) {
	case 0x0000: return 1234;          // fixed pattern
	case 0x0001: return 250;           // synthetic wind speed
	case 0x0002: return 900;           // 0x0384 — byte-order probe (FR-MB25)
	case 0x0003: return 0;
	case 0x0004: return 511;
	case 0x0005: return 3;             // synthetic status bits
	case 0x0006: return 0x0107;        // build/version pattern (FR-S32 shape)
	case 0x0007: return (uint16_t)uptime_s;
	case 0x0008: return mb_crc_error_count();
	case 0x0009: return mb_served_count();
	case 0x000A: return 42;
	case 0x000B: return 80;
	case 0x000C: return mb_fe_count();
	case 0x000D: return mb_ne_count();
	case 0x000E: return mb_ore_count();
	case 0x0010: return mb_last_bad(0);
	case 0x0011: return mb_last_bad(1);
	case 0x0012: return mb_last_bad(2);
	case 0x0013: return mb_last_bad(3);
	default:
		*ok = false;
		return 0;
	}
}

static const mb_config_t cfg = {
	.address = 30,
	.holdings = holdings,
	.n_holdings = sizeof(holdings) / sizeof(holdings[0]),
	.input_read = input_read,
	.cross_validate = cross_validate,
};

int main()
{
	SystemInit();
	funGpioInitAll();
	mb_init(&cfg);

	const uint32_t second_ticks = FUNCONF_SYSTEM_CORE_CLOCK;
	uint32_t t0 = SysTick->CNT;

	while (1)
	{
		mb_poll();
		if ((uint32_t)(SysTick->CNT - t0) >= second_ticks)
		{
			t0 += second_ticks;
			uptime_s++;
		}
	}
}

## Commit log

2026-06-22 commit again
    [windmeter-modbus-interface.kicad_pcb, windmeter-modbus-interface.kicad_sch]
2026-06-22 Update PCB
    [windmeter-modbus-interface.kicad_pcb, windmeter-modbus-interface.kicad_sch]
2026-06-27 Added power circuit
    [windmeter-modbus-interface.kicad_sch]
2026-06-28 First scaffolding
    [windmeter-modbus-interface.kicad_sch]
2026-07-02 Design: wind sensor brainstorm results and TDS v0.6
    scratchBook.md — brainstorm session results:
    - Power supply: DB20x bridge (polarity protection only) + HLK-K7803
    with capacitor selection; LC output filter on TODO
    - Anemometer input: RC debounce (10k/100nF), pull-up, zener clamp
    - Wind direction: 11k pot ratiometric to 3.3V, 10-bit ADC (0.35°/LSB),
    RC filter on pot supply; no external reference (SOIC-8 has no VREF+)
    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
2026-07-03 Software: architecture, driver dev plan, HIL harness, phases 0-2 verified
    design/
    - softwareArchitecture.md: ISR-minimal super-loop baseline (agreed):
    capture-only ISRs, main-loop services, structural snapshot coherence,
    RAM/flash/latency sizing, module split mapped to drivers
    - driverDevelopment.md: 3-driver plan (wind speed, wind direction,
    Modbus RTU) with per-phase HIL test matrices tied to TDS IDs;
    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
2026-07-03 Modbus RTU driver: 26/26 TDS matrix on TTL rig; zero-ISR architecture
    software/drivers/modbus_rtu/ (new)
    - Slave driver implementing the TDS 2 layer: framing/CRC, t3.5 gap
    detect, address/broadcast filtering, FC03/04/06/16, exceptions
    01/02/03, no-clamp rejection, atomic FC16, quantity/bytecount
    validation, big-endian data + LE CRC, FC06 echo / FC16 confirm,
    app-owned register table with min/max + cross-validate hook (FR-S31)
    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
    [windmeter-modbus-interface.kicad_sch]
2026-07-03 Firmware integration stages A-F: TDS-complete product firmware, HIL-verified
    - integrationPlan.md (new): phase-4 plan with per-stage exit criteria and
    results A-F, M2K+Saleae-as-long-as-possible principle, hardware-gated
    test set (transceiver rig + real-PCB tables)
    - TDS.md: open item documenting the volatile-register coherence
    discussion (north offset / cut-off classification, persistence costing
    ~600 B, design rule) - decision deferred, spec stays v0.6
    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
2026-07-03 Design: combined-sensor variant feasibility documented, decision deferred
    - integrationPlan.md §10: one build serving both sensors is comfortably
    feasible (pins/flash/RAM/timing all green); the two real conflicts are
    spec-level (30005 per-build meaning -> direction raw view to 30013;
    identity needs build type 0x03 + an FR-S03 address pair). Recommended
    path: introduce wind_combined as a THIRD variant, retire single-sensor
    builds only after it passes the full acceptance suite.
    - TDS.md §5: matching open item with the spec-impact list; v0.6 unchanged.
    - integrationPlan.md §5: stale rig row corrected — pulse stimulus is
    M2K W2 (AWG), not DIO1 (single-pattern-buffer limitation,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
2026-07-04 Update PCB Design
    [windmeter-modbus-interface.kicad_pcb, windmeter-modbus-interface.kicad_sch]
2026-07-05 Repository documentation: README, changelog, contributing, licenses
    Root docs adapted from the tester-repo templates to this project:
    - README: device overview, variant/address table, project status with
    pointers into the design chain, hardware summary, register-map summary,
    repo layout, build/flash/test instructions (incl. acceptance suite and
    submodule clone), related repositories
    - changelog: project history to date under [Unreleased] (design chain,
    TDS v0.6, drivers with HIL results, firmware stages A-F, HIL harness);
    release tagging deferred to RELEASES.md's fw-v<N> process
    - contributing: correct repo URL, requirements-first workflow (TDS IDs),
    build/test expectations, *_te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
    [windmeter-modbus-interface.kicad_pcb, windmeter-modbus-interface.kicad_sch]
2026-07-05 Updated text on PCB design
    [windmeter-modbus-interface.kicad_pcb]
2026-07-06 Modbus TX push-pull fix; MAX3485 rig verified incl. register matrix
    Ship-blocker caught in the first transceiver session: TX phase was
    still open-drain from the shared-TTL-wire days (its pull-up supplied
    the highs). Behind the MAX3485, RO tri-states while DE is high, nothing
    pulls the node up, and every response left as a 30 ms break while
    reception/DE/shifting stayed perfect. The PCB has no pull-up on
    MB-TX/RX either — the TTL rig had masked it. Fix: push-pull AF in
    mb.c (mirrors debug_uart); contention-free since RO is high-Z for
    exactly the DE window. FW_VERSION stays 1 (unreleased).
    Verified through the real transceiver, tester as master:
    - rs485_check.py (new, passive wire judge): 8/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
2026-07-06 Direction build validated over RS-485; byte-exact raw-master suite
    Generalizes the register matrix for both variants and adds the
    second-MAX3485 raw master, completing §9.1 for the direction build.
    - rs485_regs_check.py: --build {speed,direction} / --slave. Build-aware
    input-register active/zero map (direction: ident 0x0201, speed regs +
    pulse-age/gust read 0, raw ADC in range, no DIR_FAULT) and a
    direction-only block — 40001 north offset applied to the reported
    angle with exact 3600 wraparound (90/180/360 deg, 0 LSB error).
    Served-counter accounting keyed to the actual DUT address.
    Direction: 72/72 at addr 31. Speed unchanged: 62/62.
    - rs485_raw_check.py (new): M2K DIO0->DI,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
2026-07-06 Add consolidated HIL test report
    software/hil/testReport.md: single record of every hardware-in-the-loop
    test with setup, expected result, pass criteria, and verdict — the
    artifact that previously only existed scattered across the check-script
    docstrings, hil/README.md, driverDevelopment.md, and integrationPlan.md.
    Structure: summary matrix; a Test setup preamble (instruments,
    environments, and the three rigs' wiring — TTL, MAX3485, and the
    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
2026-07-09 Add wind_combined variant: one slave serving both sensors
    Third build (integrationPlan §10) at address 32/37, build byte 0x03,
    serving anemometer + vane from a single Modbus slave.
    Mechanism:
    - src/sensors.h maps the three mutually-exclusive -D SENSOR_WIND_*
    selectors to capability macros HAVE_WIND_SPEED / HAVE_WIND_DIRECTION
    (combined sets both) + BUILD_TYPE. Everything keys off the capabilities.
    - meas_init/meas_service split into per-sensor meas_speed_*/meas_dir_*
    (both run each loop, sharing the 40002 window boundary) — one build
    linked both would otherwise collide on duplicate symbols.
    - avg.c restructured from shared ring indices to a per-sensor cursor_t
    (cur_s/cur_d): on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
    [main.c]
2026-07-09 wind_combined: byte-exact raw-suite vectors green (§9.1 complete)
    rs485_raw_check.py gains --build combined (default slave 32; poller
    restart maps combined -> direction, the only valid tester poll type).
    Run at address 32 via the second-MAX3485 M2K raw master:
    - split frames 10/10 (DUT CRC counter +20)
    - garbage floods 3/3 (10x 2 s, 60 s soak, 10x 400-byte oversize)
    - baud margin answered to +-3%
    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
2026-07-09 FR-S38 float-fault + recovery over transceiver — §9.1 fully closed
    rs485_float_check.py (new): asserts the wind-direction float-fault and its
    sticky recovery over RS-485 via the tester API. --expect fault | driven,
    --build direction | combined (dir raw at 30005 / 30013 respectively).
    Validated on the combined build @ 32 (2026-07-08):
    - PA2 wiper lifted -> DIR_FAULT (status bit 2) set, dir_instant/dir_avg
    read the 65535 sentinel, detected regardless of the drifting floating-
    pin ADC; speed side unaffected (ident 0x0301). Fault 4/4.
    - PA2 re-driven -> sticky fault clears, dir_instant returns to 181.5°.
    Recovery 4/4.
    The wd_wiper_floating detector + fault path is the identical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
2026-07-09 FR-S39: persist holding registers to flash; TDS three-variant fixes
    Persistence (the long-deferred TDS §5 decision, resolution (c), all four
    holding registers):
    - persist.c/h: flash-emulated store (CH32V003 has no EEPROM) — two 64-byte
    pages in the top 128 B (above the NFR-RES01 code gate), one 16-byte CRC'd
    record per page, two-page ping-pong, newest-sequence-wins, save-on-change,
    read-back-verified with a bounded retry. Power-loss atomic: the current
    record stays valid until the new one commits. Erase+program follows the
    ch32v003fun flashtest sequence.
    - regs.c: regs_init seeds the holdings from flash (blank/corrupt -> §2.8
    defaults, so FR-S21's defined state still holds);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
    [main.c]
2026-07-09 Add comprehensive Doxygen documentation to all headers + minimal Doxyfile
    Every project header now carries Doxygen (JavaDoc @-tags): a @file block
    folding in the design rationale with TDS requirement IDs (FR-*) and @ref
    cross-links, and @brief/@param/@return/@note/@warning/@see on every public
    function, macro, typedef, struct and struct member. Comments only — the
    preprocessed code is byte-for-byte identical (all three firmware variants
    build to identical flash sizes: 4200/6684/7392 B).
    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
2026-07-09 Docs: add design/README index, fold design docs into Doxygen site, refresh root docs
    - design/README.md (new): indexes the design-document chain
    (scratchBook → TDS → architecture → drivers → integration), the UML
    diagrams, the three build variants, and how it wires into the Doxygen
    site / HIL report / contributing flow.
    - Doxyfile: folds the design docs (TDS, integration plan, architecture,
    driver development, scratchbook) + HIL README/report + governance docs
    in as pages, with README.md as the landing page; IMAGE_PATH renders the
    architecture diagrams; *.md/*.puml patterns resolve the cross-links.
    Zero warnings; the design pages appear in the nav tree.
    - README.md: TDS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
2026-07-11 FR-S40: runtime + persistent anemometer calibration (40005/40006)
    Move the anemometer calibration from the compile-time-only WS_C_SCALED to
    two persistent holding registers so one firmware image serves any
    anemometer — no rebuild, calibrate over Modbus, survives power cycles.
    - 40005 = calibration factor C (0.001 m/rotation, 1..6553, default 980),
    40006 = pulses per rotation (1..1000, default 1). Compile-time values are
    now the factory defaults; the running values are the registers.
    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
    [windmeter-modbus-interface.kicad_pcb]
2026-07-12 TDS v0.9: promote as-built hardware (§4) from KiCad; resolve open items
    Add §4 Hardware sourced from the as-built KiCad PCB — normative MCU
    pin/net map, RS-485 front-end, 24V PoE power chain, sensor front-ends,
    connectors, and the anemometer calibration derivation. Renumber NFRs→§5,
    Open items→§6.
    Walk through and close/narrow the §6 open items: response latency measured
    (4-5 ms), temperature range bounded by as-built parts, direction accuracy
    firmware-closed, volatile-register and combined-variant decisions recorded.
    Reconcile stale notes with the shipped firmware: FR-MB23 remap-switching
    (not HDSEL), FR-S27 pulses-per-rotation now runtime-configurable (FR-S40).
    Record as-built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
    [windmeter-modbus-interface.kicad_sch]
2026-07-12 HIL: extend rs485_regs_check to 6 holdings; land NFR-TST01 pytest stubs
    rs485_regs_check.py: cover the 40005/40006 calibration pair (FR-S40) —
    FC03 defaults [0,1000,10,4,980,1] + edge 0x0006, FC06 range edges/rejects,
    FC16 6-register atomicity, the calibration-reset status behaviour (re-asserts
    on speed/combined, inert on direction per FR-MB27), and --speed-live
    proportional scaling (ppr quarters, C doubles) awaiting a PC1 source.
    acceptance/test_nfr_tst01.py: rig-gated stubs for the NFR-TST01 backlog
    (reset matrix, latency histogram, FR-S14 alternating stimulus, 5-ratio
    divider sweep, VDD ratiometric sweep) — skipped by default, XFAIL until
    their scripts exist; latency + VDD wired to r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
2026-07-12 HIL report: record the 2026-07-12 live-sensor session
    Add the "Live-sensor rig (real anemometer + vane over RS-485)" results
    table: LIVE-REGS (6-register matrix, 92/97, no firmware defect — the 5
    non-passes are persisted field config + bench state + one FR-S30 timing
    assertion), LIVE-SPEED (FR-S06/S40 formula on live pulses, 29/29, closes
    the deferral), LIVE-DIR-STAB (FR-S10 span 0), LIVE-DIR-FLOAT (FR-S38 fault
    + recovery on the real vane).
    Flip the FR-S40 live-pulse row DEFERRED -> DONE; log the FR-S30 immediate
    bit0 re-assert as a non-blocking item to investigate. Totals 74->78 / 72->76.
2026-07-12 Docs: update architecture + firmware README for the three-variant firmware
    softwareArchitecture.md: rework from the two-build baseline — sensors.h
    capability-macro gating in scope (§1), per-capability measurement services
    in the loop sketch (§2), a new §3 decision (combined build runs both
    sensors in one super-loop pass with zero new concurrency: per-sensor avg
    cursors, 30005/30013 split, latency unchanged), stale HDSEL/RX-ISR wording
    reconciled with the shipped remap-switching discipline, §6 module split
    extended (sensors.h, avg.c, persist.c, in-place mb.c), and as-built sizes
    for all three variants in §5 (speed 4408/908, direction 6824/916, combined
    7604/1216 B vs the NFR-RES01 ceil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
